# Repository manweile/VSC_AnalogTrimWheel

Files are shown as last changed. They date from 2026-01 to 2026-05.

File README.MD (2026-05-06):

# Analog Trim Wheel

A microcontroller for MSFS Flight Simulator trim tab control  

## About

I had been using my Thrustmaster TWCS dial axis as the trim wheel controller in Microsoft Flight Simulator.  
However, it is way to small of diameter - the sensitivity makes it nearly impossible to use.  
Trying to adjust the sensitivity response just wasn't working either.  

So I went searching for a microcontroller project and found [Trim Wheel Pro](https://makers-point.com/3d-prints/trim-wheel-pro/).  
The large diameter wheel and 360 degree non-contact angle sensor attached to it were exactly the solution I needed.  
The Arduino Pro Micro met my needs for the USB HID device. Since I am a retired developer, programming the Arduino was no issue.  
However, I did not own a 3d printer at the time. My son-in-law owns several, he borrowed me one, and I ended up buying a newer model of it.  

This project was also as much for learning how to break free of Microchip Studio as building a trim wheel controller.  
Refer to the [Environment README](https://github.com/manweile/VSC_AnalogTrimWheel/blob/master/Documentation/Programming%20Environment/README.MD) file for details.  

Bottom line, this project gave me a proper trim wheel control for MSFS and will make future AVR mcu development far easier.  

## Bill of Materials

|Item|Count|Link|Part Number|
|-|-|-|-|
|Rotary Hall Angle Sensor|1|[Rotary Hall Angle Sensor](https://www.aliexpress.com/item/4000143910873.html)|P3022-V1-CW360|
|Arduino Pro Micro|1|[Arduino Pro Micro](https://www.amazon.ca/ATmega32U4-Replace-ATmega328-Leonardo-Interface/dp/B0FLLNVNFL)|Arduino Pro Micro 5V|
|M3 Bolts & Nuts|1|[Glarks](https://www.amazon.ca/dp/B01J7NM9JA?ref=ppx_yo2ov_dt_b_fed_asin_title&th=1)|Glarks 230 Pc M3 Bolts and Nuts|
|White Lithium Grease|1|[White Lithium Grease](https://www.amazon.ca/dp/B004X70LZA?ref=ppx_yo2ov_dt_b_fed_asin_title)|Lucas White Lithium Grease|
|Creality Hi Combo|1|[Creality Hi Combo](https://www.reprapwarehouse.com/)|Creality Hi Combo|
|SWD Breakout Board|1|[Adafruit SWD Cable Breakout Board](https://www.adafruit.com/product/2743)|2743|
|AVR ISP Adapter|1|[Adafruit AVR 6 Pin ISP Adapter](https://www.adafruit.com/product/1465)|1465|
|Female Headers|10|[Sparkfun Female Headers](https://www.sparkfun.com/products/115)|PRT-00115|
|Mini Pushbutton Switch|1|[Sparkfun Mini Pushbutton](https://www.sparkfun.com/products/97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)|COM-0097|
|Atmel-ICE Debugger|1|[Digikey Atmel-ICE Basic](https://www.digikey.ca/en/products/detail/microchip-technology/ATATMEL-ICE-BASIC/4753381?productid=4753381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)|ATATMEL-ICE-BASIC-ND|

## Todo's

1. remove usb serial port so device appears solely as HID-compliant game controller/USB input device
   1. this will require using Atmel-Ice for uploading
2. rename to trim wheel pro
   1. this will require changing boards.txt entries

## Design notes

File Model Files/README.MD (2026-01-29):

# 3D Printing for Analog Trim Wheel
## Source
https://www.printables.com/model/709536-trim-wheel-for-flight-simulator-hall-effect-sensor

## Printers
Creality Hi Combo

## Filaments
PETG and PLA

## Slicer Software
Creality Print 7.0

## Instructions
No supports for all printed objects.  
This did require some orientation changes, depending on which part.  
Used 0.12 mm layer height for both filaments.  

### Base
Printed in black PLA and PETG.  
Oriented on bottom face.  

### Lid
Printed in black PLA and PETG.  
Oriented on back face.  
Creality Print kept giving unsupported cantilevers error when oriented on top face or 45 degrees face.  
PETG also give me grief with extraneous filaments, especially in the nut pockets.  
Required lowering print speeds (initial and general), max extruder temperature, and infill pattern (needed gyroid).  
This could all be result of using Creality printer with a generic PETG.  
The designer used a Prusa MK3S at 0.2mm layer height.  

### Wheel
I printed the wheel in PLA only because I had that in white.  
Printing in white allowed me to write (with marker) on the wheel.  
A further modification could be use the embossing feature in Creality Print, oriented on non-shaft face.  
The flat keyed shaft hole did a very small ridge in it (where the wheel transitions to axle) which I had to remove.  

### Tensioner
Printed in black PLA and PETG.  
Oriented on side, with nut pocket opening exposed.  
For PETG, required inner & outer brim.  
PETG also had plate adhesion issues - Creality Print gave "please apply glue before print" warning.  
I didn't and did have the print job become unstuck several times until I increased bed temperature to max.  

### Spacer
Printed in black PLA and PETG.  
For PETG, required inner & outer brim.  
PETG also had plate adhesion issues - Creality Print gave "please apply glue before print" warning.  
I didn't and did have the print job become unstuck several times until I increased bed temperature to max.  

### Clamp
I got the clamp from Creality Cloud, but I'm sure you can find something suitable elsewhere.  

Printed in both PETG & PLA, and in black and white.  
Totally your choice of filament and colour.  

2 different size options  
- 2.75 inch vise
- 3 inch vise

Make sure to print the vise WITHOUT supports!  
Screw hole will be plugged up if you do, and good chance will not be usable.  

## Overall Results
PLA was better than PETG.  
- No filaments in nut pockets
- Faster
- No plate adhesion issues

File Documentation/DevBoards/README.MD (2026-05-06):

# Custom USB Device

The promicro does NOT have it's own entry in the arduino boards.txt file.  
This means when you hook up an Arduino Pro Micro, what you will see in Devices & Printers is Arduino Leonardo.  

## IMPORTANT

Creating a promicro entry in boards.txt has ramifications!
Boards.txt defines the characteristics and parameters of different Arduino boards and microcontrollers.  
It tells the Arduino IDE and Arduino-CLI  how to:

- compile
- link
- upload code

This WILL impact any VS Code c_cpp_properties.json, tasks.json or launch.json functionality for Arduino-CLI.  
Specifically any inputs looking for fully qualified board name arduino:avr:promicro or build directory arduino.avr.promicro  

A Pro Micro is just a renamed Leonardo!  
You only want to change the .name, .pid.3, .build.pid, .build.usb_product, and .build.usb_product values.  
You can optionally add promicro.build.usb_manufacturer.  

## Setting custom USB device name

1. Modify Arduino Board Configuration
   1. Ensure Arduino IDE is closed
   2. Locate the boards.txt file  
      Usually in C:\users\USERNAME\AppData\Local\Arduino15\packages\arduino\hardware\1.8.x,
      where USERNAME is your user name and 1.8.x is the version of Arduino AVR Boards installed by Arduino IDE.  
      You can get the version by checking Boards Manager in Arduino IDE.  
   3. Create a custom board entry  
      Copy the existing leonardo (and not leonardoeth) definition lines to end of board.txt file.  
      In the new custom board entry, edit all "leonardo" entries to "promicro"  
   4. Change promicro.name=Arduino Leonardo to promicro.name=Arduino Pro Micro
   5. Change promicro.pid.1=0x8036 to promicro.pid.1=0x8035
   6. Change promicro.build.pid=0x8036 to leonardo.build.pid=0x8035  
      You want a unique pid.  
      It's a good idea to search through out boards.txt to make sure 0x8035 is not in use.  
      If it is, do a regex search for the last digit or last two digits.  
   7. Change promicro.build.usb_product="Arduino Leonardo" to promicro.build.usb_product="Arduino Pro Micro"
   8. Optional - add promicro.build.usb_manufacturer="Arduino" underneath promicro.build.usb_product="Arduino Pro Micro"
   9. Save the boards.txt file
   10. Ensure your pro micro is plugged into USB on computer
   11. Open Arduino IDE
   12. Find & select the new custom board name Tools > Board Manager > Arduino AVR Boards
   13. Upload a sketch (preferably the analog trim wheel sketch!)
   14. Close Arduino IDE

## Resulting Arduino Pro Micro Entry in Boards.txt

promicro.name=Arduino Pro Micro  

promicro.vid.0=0x2341  
promicro.pid.0=0x0036  
promicro.vid.1=0x2341  
promicro.pid.1=0x8035  
promicro.vid.2=0x2A03  
promicro.pid.2=0x0036  
promicro.vid.3=0x2A03  
promicro.pid.3=0x8035  

promicro.upload.tool=avrdude  
promicro.upload.protocol=avr109  
promicro.upload.maximum_size=28672  
promicro.upload.maximum_data_size=2560  
promicro.upload.speed=57600  
promicro.upload.disable_flushing=true  
promicro.upload.use_1200bps_touch=true  
promicro.upload.wait_for_upload_port=true  

promicro.bootloader.tool=avrdude  
promicro.bootloader.low_fuses=0xff  
promicro.bootloader.high_fuses=0xd8  
promicro.bootloader.extended_fuses=0xcb  
promicro.bootloader.file=caterina/Caterina-Leonardo.hex  
promicro.bootloader.unlock_bits=0x3F  
promicro.bootloader.lock_bits=0x2F  

promicro.build.mcu=atmega32u4  
promicro.build.f_cpu=16000000L  
promicro.build.vid=0x2341  
promicro.build.pid=0x8035  
promicro.build.usb_product="Arduino Pro Micro"  
promicro.build.usb_manufacturer="Arduino"  
promicro.build.board=AVR_LEONARDO  
promicro.build.core=arduino  
promicro.build.variant=leonardo
promicro.build.extra_flags={build.usb_flags}

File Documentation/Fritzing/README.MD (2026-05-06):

# Fritzing

Yeah, I know some dev's look down on Fritzing, and I don't blame them. The program does indeed have drawbacks.
But it's biggest pro is the intuitive breadboard view, and the ease of use compared to ANY cad program.

## JTAG and ISP

Atmel wants to gouge a pretty penny for connectors, which I refuse to pay.  

Luckily, Adafruit has a [SWD breakout](https://www.adafruit.com/product/2743) that you can adapt for JTAG use.  
All that you need to do is pay attention to the pin mapping specified in Atmel-ICE documentation.  

Adafruit also has an [ISP breadboard adapter](https://www.adafruit.com/product/1465), perfect for ISP.  

Both breakouts are for use with Atmel-ICE with flat jtag/isp cable.  
You can attach both the 10 pin header and 6 pin header.  

## Micro

The micro does have a dedicated ISP header, you can use it or the regular edge pins.  
For JTAG, use the regular edge pins.
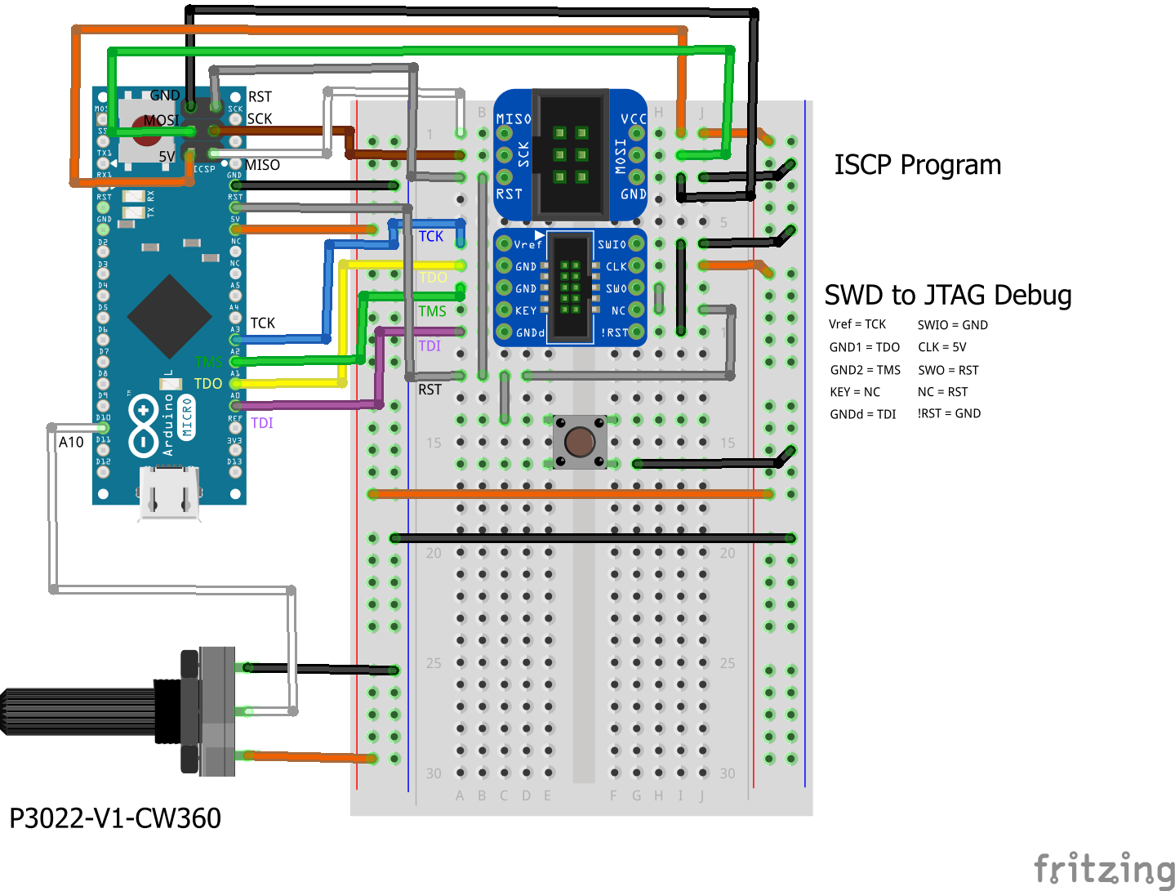
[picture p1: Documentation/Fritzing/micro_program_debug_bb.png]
Micro JTAG ISP


If you put anything in the regular edge pins next to the ISP header, you can't use the Atmel-ICE flat cable ISP connector.  
It's got a keyway that protrudes, and will prevent you from getting proper electrical connection.  
Hence the ISP breadboard adapter.  

## Pro Micro

The promicro does not have a dedicated ISP header, use the regular edge pins.  
For JTAG, use the regular edge pins.  

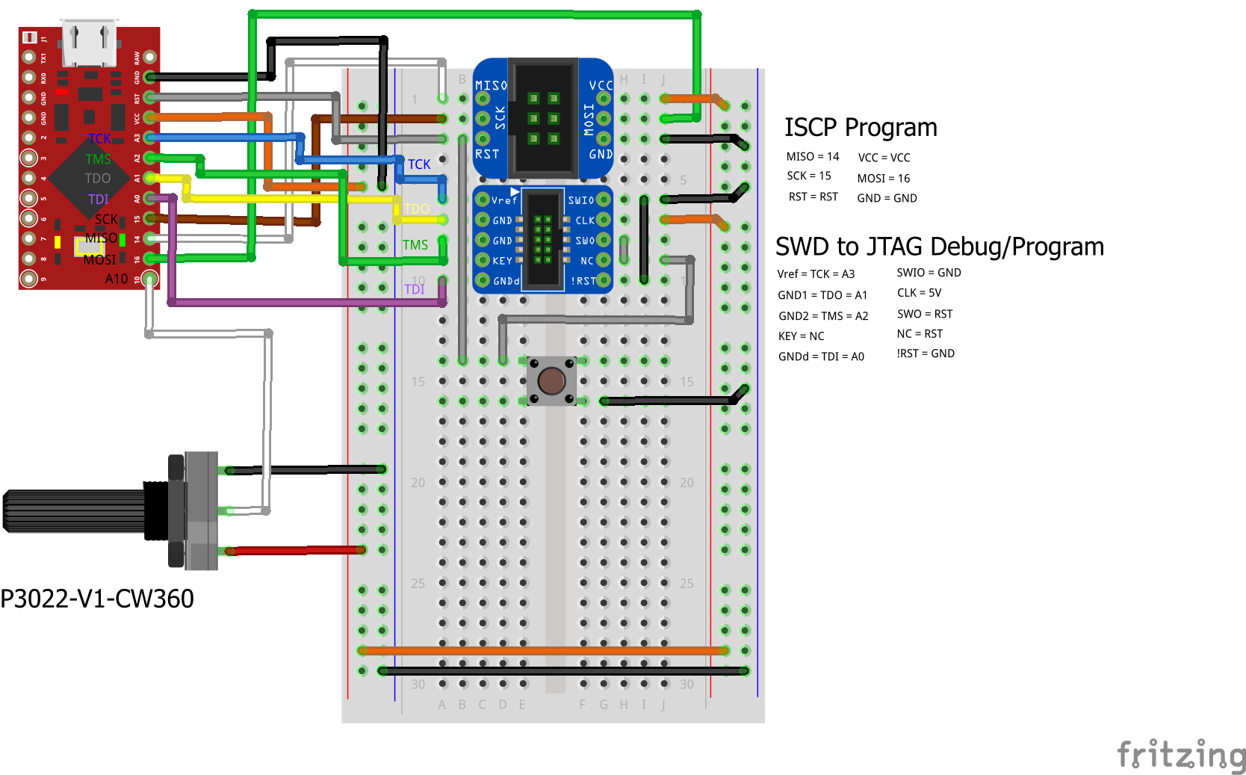
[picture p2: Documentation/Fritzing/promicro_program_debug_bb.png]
Promicro JTAG ISP


### SWD for JTAG and ISP

My Atmel-ICE flat cable ISP developed a broken wire somewhere, which rendered the ISP connection unusable.  
Fortunately, after reviewing the Atmel-ICE documentation, I realized a SWD header can supply signal for both JTAG and ISP.  

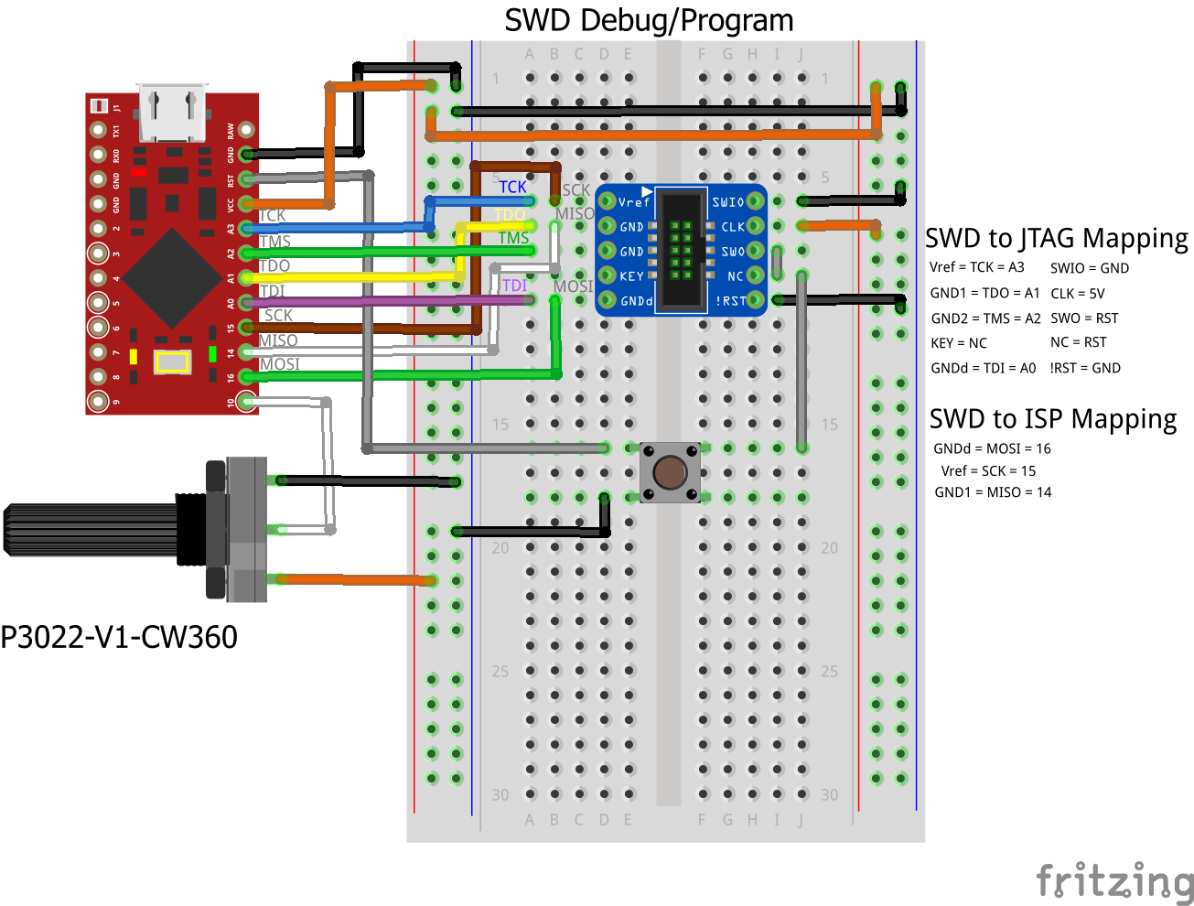
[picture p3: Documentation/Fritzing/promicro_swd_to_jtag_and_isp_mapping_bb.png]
Promicro SWD Debug/Program


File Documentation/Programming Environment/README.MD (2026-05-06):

# Programming Environment

## About

This project was as much for learning how to break free of Microchip Studio as building a trim wheel controller.

## Tools Used

- Atmel-ICE
- Arduino IDE
- avr toolchain (avr-gdb, avr-gcc, avrdude)
- Arduino-CLI
- AVRDUDESS (optional, but recommended)
- VS Code & Extensions
- AVaRICE
- MYSYS2
- WSL2

## Atmel-ICE

I know there are other hardware programmer/debuggers available, but the Atmel-ICE is for AVR/SAM mcu's.  

The Arduino Pro Micro and Micro both have JTAG and ISP pins broken out.  
So do the Mega2560 and Uno - but you can't easily use them for a HID application.  
I am presuming you've already installed drivers for you Atmel-ICE per Microchip's [install instructions](https://www.microchip.com/en-us/development-tool/atatmel-ice).  

## ArduinoIDE

Let's face it, the [Arduino IDE](https://www.arduino.cc/en/software/) is the sandbox.  
It's where you start, but you sure as hell out grow it quickly.  
It does have it's uses though - quick way to get the avr tools (avr-gcc, avr-gdb, avrdude), third party libraries, board management, etc.  
You're going to need it installed anyways if you want to do arduino coding with Microchip Studio.

## AVR Toolchain

### Arduino AVR Toolchain

I prefer the arduino avr toolchain. Why?  
Because it's maintained, compiled for Windows, works with my arduino boards, it's reasonably documented, it's easy to update.  
You can update the Arduino IDE itself, which might update your tool chain. This is the easiest way to update.  

Personally, I like the 7.3.0-atmel3.6.1-arduino5 toolchain that came with installing Arduino IDE 2.2 version.  

You can [manually update the toolchain](https://github.com/arduino/toolchain-avr/tags), just download the zip file for the version you want.  
You WILL have to compile for your preferred OS, and that's an exercise I will leave to you.  
Look at the Readme.md file in your download for details.  

Of course you will also have to install the new compile in the correct location for your OS.  

- On Windows: C:\Users\USERNAME\AppData\Local\Arduino15\packages\arduino\tools
- On Linux (Ubuntu): /HOME/USERNAME/.arduino15/packages/arduino/tools/

Just remember if you any environment variables looking at toolchain path locations, you'll need to edit them!  

### Manual AVR toolchain

Many variations here, [AVR Toolchain on Windows](https://www.tonymitchell.ca/posts/setup-avr-toolchain-on-windows/) is a good source of info & guidance.  

The major advantage of manually installing the toolchain is the pathing.  
You get to choose directory names, which means shorter and not highly specific.  

C:\AVR\avr8-gnu-toolchain\bin  
vs  
C:\Users\USERNAME\AppData\Local\Arduino15\packages\arduino\tools\avr-gcc\7.3.0-atmel3.6.1-arduino5\bin  

Downside is you might need to do some Linux on Windows setup - be it WSL2, Cygwin, MYSYS2, MINGW, etc.  
Again, don't forget about those environment variables!  

## AVRDUDE

[Avrdude (AVR Downloader Uploader)](https://avrdudes.github.io/avrdude/) is a program for downloading and uploading the on-chip memories of Atmel’s AVR microcontrollers.  
It's what Microchip Studio and Arduino IDE (and Arduino-CLI) use under the hood to get code onto your mcu.
Avrdude is a command line application, and easily used with VS Code tasks.

It comes with the Arduino AVR toolchain, which is a good reason to install the Arduino IDE.  
Otherwise you have to select a version from [Avrdudes](https://github.com/avrdudes/avrdude/releases) and manually install.  

## Arduino-CLI

Arduino-CLI is an all-in-one command line solution that's the hidden motor in Arduino IDE.  
Arduino-CLI provides Boards/Library Managers, sketch builder, board detection, uploader, and many other tools.  
However, an Arduino IDE installation does NOT give you command line access. Not sure why Arduino did that.  
This forces you to a manually install if you want to leverage it into VS Code.  
The [documentation](https://docs.arduino.cc/arduino-cli/) is adequate, but sure would like to find a well formatted pdf.

The beauty of arduino-cli is you can do so much with it from VS Code tasks!  
What's more, Arduino replaced make with arduino-cli compile functionality, it's actually easier to compile with.  

### arduino-cli.yaml

The yaml configuration file is probably the most important step in the arduino-cli install process.  
It's also something that could use better [documentation!](https://docs.arduino.cc/arduino-cli/configuration/)  

I found the important sections of the yaml file were:

- board manager
  - additional urls
        This where every board you want to work with needs to be.  
        The listing is also exactly what you put into the Arduino IDE preferences Additional boards manager URLS.  
        Literally copy from and paste into yaml file.
- directories
  - builtin
    - libraries
        The path to your builtin Arduino Libraries.  
        C:\Users\USERNAME\AppData\Local\Arduino15\libraries
  - data  
        the path to your Arduino directory used to store Boards/Library Manager index files and Boards Manager platform installations.  
        C:\Users\USERNAME\AppData\Local\Arduino15
  - downloads  
        directory used to stage downloaded archives during Boards/Library Manager installations.  
        C:\Users\USERNAME\AppData\Local\Arduino15\staging
  - user  
        the equivalent of the Arduino IDE's "sketchbook" directory.  
        You can copy from Arduino IDE preferences and paste it into yaml file.

## AVRDUDESS

[AVRDUDESS](https://blog.zakkemble.net/avrdudess-a-gui-for-avrdude/) is a gui wrapper for avrdude.  

Optional, but recommended, it is quite useful when you have something kinda one off thing that you don't have a VS Code task configured for.

- restoring boot loaders
- setting fuses  
- general mcu problem solving (ie unbricking!)

For fuses, you just have to be aware that in AVRDUDESS, a 1 for fuse actually means unset, and a 0 means set!  
In this aspect Microchip Studio's device programming dialog is actually more intuitive ... if you don't mind the baggage that comes with.  

AVRDUDESS is Windows centric, but you can get it onto Ubuntu - refer to the [AVRDUDESS readme](https://github.com/avrdudes/avrdude/blob/main/README.md).

## VSCODE

Why?

- Because it's hella easier to use than Microchip Studio
- It's better than Arduino IDE
- It's multi-OS
  - Windows
  - Ubuntu (either free-standing or via WSL2)
- I have 10 years of experience with it
- Fantastic amount of extensions
- And it's free!  

Far and away the devil I know and comprehend.  
Sure the documentation could be better, but hey, isn't all software like that?

### Extension Successes

- [C/C++](https://marketplace.visualstudio.com/items?itemName=ms-vscode.cpptools)  
      Required, need this for Intellisense and debugging.
- [Command Variable](https://marketplace.visualstudio.com/items?itemName=rioj7.command-variable)  
      Optional, but highly recommended for command and/or variable substitution in tasks and launch json files.  
      Allows you you really leverage external functionality.  
- [WSL](https://marketplace.visualstudio.com/items?itemName=ms-vscode-remote.remote-wsl)  
      Optional if you want to build Linux applications that run on WSL without the hassle of dual booting or a full virtual machine.  
      Required to use Ubuntu AVaRICE with Atmel-ICE, but comes with usb connectivity issue to the Atmel-ICE. More on that later.  

### Extension Failures

- [PlatformIO](https://marketplace.visualstudio.com/items?itemName=platformio.platformio-ide)  
    Couldn't get it to work for my AVR mcu's or with Atmel-ICE.  
    From the PlatformIO documentation, it really looks like really optimized for SAM/ARM mcu Arduino's, but not AVR mcu's.  
    Also looks like might be the go to for ESP32 mcu's which I do have.  

- [Arduino Community Edition](https://marketplace.visualstudio.com/items?itemName=vscode-arduino.vscode-arduino-community)  
    Gave me nothing but grief.  
    Actually bricked my micro and pro micro boards.  
    Appears to be really optimized for SAM/ARM mcu Arduino's, but not AVR mcu's.

## System Environment

### Variables

You can create and use custom environment variables that your c_cpp_properties.json, tasks.json and launch.json can use.  

Note if you update a path pointed to by a custom environment variable, you have to update the variable!  

You need to name the custom variable ARDUINO_  
Be aware that the Arduino-CLI can use custom variables too.  
Eg. ARDUINO_DIRECTORIES_USER, which is D:\MyArduino\Projects on my computer.  
Make sure you are not conflicting, refer to [configuration keys](https://docs.arduino.cc/arduino-cli/configuration/#configuration-keys) to check!

- ARDUINO_HARDWARE_BOOTLOADERS:  
    C:\Users\USERNAME\AppData\Local\Arduino15\packages\arduino\hardware\avr\1.8.2\bootloaders
- ARDUINO_HARDWARE_CORES:  
    C:\Users\USERNAME\AppData\Local\Arduino15\packages\arduino\hardware\avr\1.8.2\cores
- ARDUINO_HARDWARE_LIBRARIES:  
    C:\Users\USERNAME\AppData\Local\Arduino15\packages\arduino\hardware\avr\1.8.2\libraries
- ARDUINO_HARDWARE_VARIANTS:  
    C:\Users\USERNAME\AppData\Local\Arduino15\packages\arduino\hardware\avr\1.8.2\variants
- ARDUINO_LIBRARIES:
    D:\MyArduino\Projects\Libraries
- ARDUINO_TOOLS:  
    C:\Users\USERNAME\AppData\Local\Arduino15\packages\arduino\tools
- ARDUINO_TOOLS_AVRGCC_BIN:  
  C:\Users\USERNAME\AppData\Local\Arduino15\packages\arduino\tools\avr-gcc\7.3.0-atmel3.6.1-arduino5\bin

Now I can use these system variables in the c_cpp_properties.json, tasks.json or launch.json and NOT have to put in a long ass OS specific path.  
You still have to maintain the path no matter what, but now it's only in 1 place.  

### PATH

To use applications like arduino-cli, avr-gdb, avrdude, etc., in VSCode tasks.json and launch.json files, you must have them in your path.  
User or Environment really doesn't matter, so long as they are available.

### c_cpp_properties.json

This where you get you Intellisense from!  
Specifically, if you have 3rd party libraries, you need to put their paths here.  
Refer to:

- [C/C++ for Visual Studio Code](https://marketplace.visualstudio.com/items?itemName=ms-vscode.cpptools)  
- [C++ extension settings reference](https://code.visualstudio.com/docs/cpp/customize-cpp-settings)

### tasks.json

Tasks.json is where you get to leverage command line scripts and external tools.  
Refer to [Integrate External Tools via Tasks](https://code.visualstudio.com/docs/debugtest/tasks) for documentation.

### launch.json

Launch.json is where the debugging magic happens.  
Refer to [Launch Configurations](https://code.visualstudio.com/docs/debugtest/debugging-configuration) for documentation.  
I also found google AI searches helpful (so long as you watch out for "hallucinations").  

## AVaRICE

AVaRICE was the winner (no shit sherlock, literally made for AVR mcu's and Atmel-ICE!) over [OpenOCD](https://openocd.org/) and [pyOCD](https://pyocd.io/).  
I never tried [Bloom](https://bloom.oscillate.io/) - found out about it after I got AVaRICe working, and it's Linux only.  

The major issue with AVaRICE was operating system flavour.  
With Ubuntu, the usual sudo apt update && sudo apt upgrade -y followed by sudo apt install avarice works fine.  
The problem after that was Atmel-ICE is very much a Windows tool - interfacing across WSL2 to use the Atmel-ICE is kludgy.  
More on that in [AVaRICE on WSL2](#avarice-on-wsl2).

With Windows ... oh dear.  
The primary grief was the libhidapi library - getting it via Cygwin, MYSYS, or GetGNUWin32 proved to be impossible.  

AVaRICE github has documentation saying you can use Cygwin to compile.  
When you read closer, it's a much older version of Cygwin (cygwin 1.3.22-1).

GetGNUWin32 just didn't work. Ended up uninstalling it.  

MYSYS actually worked!  

## MYSYS2

[MYSYS2](https://www.msys2.org/) brings powerful, Linux-style development tools and package management to Windows users.  
MYSYS2 simplifies the process of creating native applications.  
Installation is straightforward, use is very easy.  

### AVaRICE on MYSYS2

AVaRICE on MYSYS2 worked when I dug into the github workflow logs.  
Beautiful template on how to compile and use AVaRICE.  
Upshot is libhidapi is replaced, but you have to compile 3 different libraries before you compile AVaRICE.  

You will have to run AVaRICE in a MYSYS2 MYSYS shell, but it works quite well, command line and in tasks/launch json files.  
The payoff is you can stay entirely in Windows - no arcane interfacing with Atmel-ICE required!  

Refer to [MYSYS2 Avarice compilation.txt](https://github.com/manweile/VSC_AnalogTrimWheel/blob/master/Documentation/Programming%20Environment/MYSY2%20Avarice%20compilation.txt)

## WSL2

Plenty of good documentation from Microsoft: [wsl2](https://learn.microsoft.com/en-us/windows/wsl/install).
Installation is straightforward, configuration can take little time, but is worth it.  
WSL2 offers a full Linux environment directly on Windows using a light weight virtual machine.  

### AVaRICE on WSL2

AVaRICE on WSL2 Ubuntu works, downside is still had to jump through some hoops to run on Windows.

- The installation of AVaRICE is quite painless
  - but have to do some fancy dancing with usbipd-win to get communication with the Atmel-ICE.
This setup is somewhat kludgey
- have to revert the usbipd configuration to restore normal Windows operation with Atmel-ICE, arduino-cli & avrdude.  

Needs further investigation to see if I can do the usbipd configuring in VS code launch and tasks operations.  

Follow the [WSL Avarice installation.txt](https://github.com/manweile/VSC_AnalogTrimWheel/blob/master/Documentation/Programming%20Environment/WSL%20Avarice%20installation.txt) file.  
Follow the [JTAG_ICE setup and use from WSL.txt](https://github.com/manweile/VSC_AnalogTrimWheel/blob/master/Documentation/Programming%20Environment/JTAG_ICE%20setup%20and%20use%20from%20WSL.txt) file to run AVaRICE on WSL2.  

Bottom line, it works, and it is a Ubuntu solution if that's your bent.  

## Other Tools

### IDES

### Microchip Studio

Microchip is no longer updating it, and promoting switching to MPLAB. No thank you.  
It's only for Microchip mcu's anyways, and really is overkill for almost all development tasks.  
What it is good for is going deep into the bare metal, registers, ports, and assembly code.  
I will grant the device programming dialog GUI is easier to use with Atmel-ICE than avrdude, and about equal with AVRDUDESS GUI.

### Visual Micro

[Visual Micro](https://www.visualmicro.com/) is a paid extension for MicroChip Studio/Visual Studio.  
While it does help MicroChip Studio, it has it's own learning curve and foibles.  
And you can't have an simultaneous install of the extension in both Microchip Studio and Visual Studio.  
It's one or the other, and furthermore, you can only swap once per month!

### Visual Studio

VS Code's big brother might be an option worth looking into.  
VSCode extensions are not Visual Studio compatible. Sure would be nice if they were.  
Personally, I'm not fond of the default layout of VS 2026 - I actually prefer older versions like 2017/2019.  
BTW, Microchip Studio is a port of Visual Studio. Not sure how Microchip pulled that off.  

### Eclipse

No, just no. Been there, done that with Java.
I find Eclipse a real PITA to configure. Don't even want to try for avr mcu's.  

### Interfacing Software

To hardware debug with Atmel-ICE, you need interfacing software between Atmel-ICE, avr-gdb, and your mcu.  

### pyOCD

[pyOCD](https://pyocd.io/) was a non-starter, I simply could not get it to work.  
A pity, because I really liked the os-agnosticism inherent to a python app.
Uninstalled, but going to keep an eye on it in case it gets usable.  

### OpenOCD

[OpenOCD](https://openocd.org/) was far more promising, but still only a partial success.  
Supposedly, Microchip Studio uses OpenOCD "under the hood".  
I couldn't get native OpenOCD to work with my Arduino Micro & Pro Micro (atmega32u4).  

Documentation is conflicting on OpenOCD working with AVR mcu's.  
It really appears to be slanted to SAM/ARM mcu's, which I don't have any of (yet).  
Keeping it around for the potential to work with ESP32 mcu's, which I do have.  

### Bloom

I never tried [Bloom](https://bloom.oscillate.io/), found it after I had AVaRICE working.  At first glance, it looks good.  
I like the Insight GUI, which is something that could rival Microchip Studio for serious bare metal work.  
The caveat with Bloom is that it is Linux only, and I already have that with AVaRICE.  
Going to keep an eye on it though for a Windows port.

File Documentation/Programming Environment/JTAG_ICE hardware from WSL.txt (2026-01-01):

Ensure your JTAG/ICE hardware is accessible within the WSL environment

#########################################################################################################
open an admin powershell terminal

#########################################################################################################
Install usbipd-win:
PS C:\Users\gmanw> winget.exe install --interactive --exact dorssel.usbipd-win
Found an existing package already installed. Trying to upgrade the installed package...
Found usbipd-win [dorssel.usbipd-win] Version 5.3.0
This application is licensed to you by its owner.
Microsoft is not responsible for, nor does it grant any licenses to, third-party packages.
Downloading https://github.com/dorssel/usbipd-win/releases/download/v5.3.0/usbipd-win_5.3.0_x64.msi
  ██████████████████████████████  4.29 MB / 4.29 MB
Successfully verified installer hash
Starting package install...
Successfully installed

#########################################################################################################
List available devices:
Before connecting arduino micro:
PS C:\Users\gmanw> usbipd list
Connected:
BUSID  VID:PID    DEVICE                                                        STATE
1-1    044f:b687  USB Input Device                                              Not shared
1-2    231d:0200  USB Input Device                                              Not shared
1-9    044f:b679  USB Input Device                                              Not shared
1-10   6655:4101  USB Input Device                                              Not shared
1-12   03eb:2141  USB Input Device, Atmel-ICE Data Gateway                      Not shared
1-19   1058:259f  USB Mass Storage Device                                       Not shared
3-2    2341:0043  Arduino Uno (COM11)                                           Not shared
3-3    07ca:313a  Live Streamer CAM 313, Live Streamer CAM313 Microphone        Not shared

Persisted:
GUID                                  DEVICE
869c6a39-3c90-472e-95d9-bf2ae29e455b  USB Attached SCSI (UAS) Mass Storage Device

usbipd: warning: USB filter 'USBPcap' is known to be incompatible with this software; 'bind --force' will be required.

#########################################################################################################
After connecting arduino micro:
PS C:\Users\gmanw> usbipd list
Connected:
BUSID  VID:PID    DEVICE                                                        STATE
1-1    044f:b687  USB Input Device                                              Not shared
1-2    231d:0200  USB Input Device                                              Not shared
1-8    2341:8037  Arduino Micro (COM24), USB Input Device                       Not shared
1-9    044f:b679  USB Input Device                                              Not shared
1-10   6655:4101  USB Input Device                                              Not shared
1-12   03eb:2141  USB Input Device, Atmel-ICE Data Gateway                      Not shared
1-19   1058:259f  USB Mass Storage Device                                       Not shared
3-2    2341:0043  Arduino Uno (COM11)                                           Not shared
3-3    07ca:313a  Live Streamer CAM 313, Live Streamer CAM313 Microphone        Not shared

Persisted:
GUID                                  DEVICE
869c6a39-3c90-472e-95d9-bf2ae29e455b  USB Attached SCSI (UAS) Mass Storage Device

usbipd: warning: USB filter 'USBPcap' is known to be incompatible with this software; 'bind --force' will be required.

#########################################################################################################
Binding atmel-ice:
PS C:\Users\gmanw> usbipd bind --busid 1-12
usbipd: warning: USB filter 'USBPcap' is known to be incompatible with this software; 'bind --force' will be required.

#########################################################################################################
Attaching atmel-ice:
PS C:\Users\gmanw> usbipd attach --wsl --busid 1-12
usbipd: info: Using WSL distribution 'Ubuntu' to attach; the device will be available in all WSL 2 distributions.
usbipd: info: Loading vhci_hcd module.
usbipd: info: Detected networking mode 'nat'.
usbipd: info: Using IP address 172.18.32.1 to reach the host.

#########################################################################################################
After attaching atmel-ice:
PS C:\Users\gmanw> usbipd list
Connected:
BUSID  VID:PID    DEVICE                                                        STATE
1-1    044f:b687  USB Input Device                                              Not shared
1-2    231d:0200  USB Input Device                                              Not shared
1-8    2341:8037  Arduino Micro (COM24), USB Input Device                       Not shared
1-9    044f:b679  USB Input Device                                              Not shared
1-10   6655:4101  USB Input Device                                              Not shared
1-12   03eb:2141  USB Input Device, Atmel-ICE Data Gateway                      Attached
1-19   1058:259f  USB Mass Storage Device                                       Not shared
3-2    2341:0043  Arduino Uno (COM11)                                           Not shared
3-3    07ca:313a  Live Streamer CAM 313, Live Streamer CAM313 Microphone        Not shared

Persisted:
GUID                                  DEVICE
869c6a39-3c90-472e-95d9-bf2ae29e455b  USB Attached SCSI (UAS) Mass Storage Device

#########################################################################################################
Verify device is listed in WSL terminal:
gerald@MSI-DESKTOP:~$ lsusb
Bus 001 Device 001: ID 1d6b:0002 Linux Foundation 2.0 root hub
Bus 001 Device 002: ID 03eb:2141 Atmel Corp. ICE debugger
Bus 002 Device 001: ID 1d6b:0003 Linux Foundation 3.0 root hub

#########################################################################################################
Install necessary Linux tools in WSL terminal:
gerald@MSI-DESKTOP:~$ sudo apt install linux-tools-generic hwdata

#########################################################################################################
Create udev rule in WSL terminal:

gerald@MSI-DESKTOP:~$ sudo vim /etc/udev/rules.d/99-avr-jtag.rules
# Atmel-ICE (EDBG)
SUBSYSTEM=="usb", ATTR{idVendor}=="03eb", ATTR{idProduct}=="2141", MODE="0666", GROUP="plugdev"

# AVR Dragon
SUBSYSTEM=="usb", ATTR{idVendor}=="03eb", ATTR{idProduct}=="2107", MODE="0666", GROUP="plugdev"

# JTAGICE mkII
SUBSYSTEM=="usb", ATTR{idVendor}=="03eb", ATTR{idProduct}=="2103", MODE="0666", GROUP="plugdev"

# JTAGICE 3
SUBSYSTEM=="usb", ATTR{idVendor}=="03eb", ATTR{idProduct}=="2140", MODE="0666", GROUP="plugdev"

save and exit

apply rules in WSL terminal:
gerald@MSI-DESKTOP:~$ sudo udevadm control --reload-rules && sudo udevadm trigger
gerald@MSI-DESKTOP:~$ sudo usermod -aG plugdev $USER

verify rules WSL terminal:
gerald@MSI-DESKTOP:~$ lsusb
Bus 001 Device 001: ID 1d6b:0002 Linux Foundation 2.0 root hub
Bus 001 Device 002: ID 03eb:2141 Atmel Corp. ICE debugger
Bus 002 Device 001: ID 1d6b:0003 Linux Foundation 3.0 root hub
gerald@MSI-DESKTOP:~$ ls -l /dev/bus/usb/001/002
crw-rw-rw- 1 root plugdev 189, 1 Dec 30 15:34 /dev/bus/usb/001/002

#########################################################################################################

Set mcu fuses:
Note: you can use avrdude/AVRDUDESS while you have the Atmel-Ice setup with usbipd.
You CANNOT with Microchip studio.

With AVRDUDESS:
open bit fuses; select OCDEN and JTAGEN to 0, HFUSE should now have 0x18, click write fuses.
To reverse, select OCDEN and JTAGEN to 1, HFUSE should now have 0xD8, click write fuses.

With avrdude cli:
avrdude.exe -c atmelice_isp -p m32u4 -F -v -v -U lfuse:w:0xFF:m -U hfuse:w:0x18:m -U efuse:w:0xFB:m
to reverse: avrdude.exe -c atmelice_isp -p m32u4 -F -v -v -U lfuse:w:0xFF:m -U hfuse:w:0xD8:m -U efuse:w:0xFB:m

With Microchip Studio Device Programming Dialog:
First you have to detach and unbind the Atmel-Ice with usbipd
Open device programming dialog
Tool: Atmel-Ice, Device: ATmega32u4 (for example), Interface: JTAG or ISP (depends on which you have hooked up and/or prefer). 
click device signature read, click target voltage read.
Select HIGH.OCDEN, select HIGH.JTAGEN, click Program.
To reverse, unselect HIGH.OCDEN, select HIGH.JTAGEN, click Program.

#########################################################################################################

Run AVaRICE in WSL Terminal:
gerald@MSI-DESKTOP:~$ avarice --edbg --jtag usb :4242
AVaRICE version 2.14svn20200906, Mar 28 2022 12:30:47

Defaulting JTAG bitrate to 250 kHz.

JTAG config starting.
Found a device, serial number: J41800082278
Reported device ID: 0x9587
Configured for device ID: 0x9587 atmega32u4
JTAG config complete.
Preparing the target device for On Chip Debugging.
Waiting for connection on port 4242.

#########################################################################################################

verify avr-gdb in Admin Powershell:
PS D:\MyArduino\Projects\VSC_AnalogTrimWheel\build\arduino.avr.micro> avr-gdb.exe .\VSC_AnalogTrimWheel.ino.elf
GNU gdb (GDB) 7.8
Copyright (C) 2014 Free Software Foundation, Inc.
License GPLv3+: GNU GPL version 3 or later <http://gnu.org/licenses/gpl.html>
This is free software: you are free to change and redistribute it.
There is NO WARRANTY, to the extent permitted by law.  Type "show copying"
and "show warranty" for details.
This GDB was configured as "--host=i686-w64-mingw32 --target=avr".
Type "show configuration" for configuration details.
For bug reporting instructions, please see:
<http://www.gnu.org/software/gdb/bugs/>.
Find the GDB manual and other documentation resources online at:
<http://www.gnu.org/software/gdb/documentation/>.
For help, type "help".
Type "apropos word" to search for commands related to "word"...
Reading symbols from .\VSC_AnalogTrimWheel.ino.elf...done.
(gdb) target remote localhost:4242
Remote debugging using localhost:4242
0x00007000 in ?? ()
(gdb)

AVaRICE in WSL Terminal output:
Connection opened by host 127.0.0.1, port 60094.

avr-gdb in Admin Powershell:
(gdb) quit
This will also terminate avarice, so you have to restart it in the WSL terminal.

#########################################################################################################

You can now debug in VS Code
NB Setting/unsetting the OCDEN and JTAGEN fuses is NOT required!
Launch avarice is a WSL terminal:
single use: gerald@MSI-DESKTOP:~$ avarice --edbg --jtag usb :4242
continuous: gerald@MSI-DESKTOP:~$ while true; do avarice --edbg --jtag usb :4243; sleep 1; done

Use launch task in VS Code

#########################################################################################################

To reverse Atmel-Ice setup:

Verify device is listed in WSL terminal:
gerald@MSI-DESKTOP:~$ lsusb
Bus 001 Device 001: ID 1d6b:0002 Linux Foundation 2.0 root hub
Bus 001 Device 002: ID 03eb:2141 Atmel Corp. ICE debugger
Bus 002 Device 001: ID 1d6b:0003 Linux Foundation 3.0 root hub

list devices in Admin Powershell terminal:
PS C:\Users\gmanw> usbipd list
Connected:
BUSID  VID:PID    DEVICE                                                        STATE
1-1    044f:b687  USB Input Device                                              Not shared
1-2    231d:0200  USB Input Device                                              Not shared
1-8    0000:0002  Unknown USB Device (Device Descriptor Request Failed)         Not shared
1-9    044f:b679  USB Input Device                                              Not shared
1-10   6655:4101  USB Input Device                                              Not shared
1-12   03eb:2141  USB Input Device, Atmel-ICE Data Gateway                      Attached
1-19   1058:259f  USB Mass Storage Device                                       Not shared
3-2    2341:0043  Arduino Uno (COM11)                                           Not shared
3-3    07ca:313a  Live Streamer CAM 313, Live Streamer CAM313 Microphone        Not shared

Persisted:
GUID                                  DEVICE
869c6a39-3c90-472e-95d9-bf2ae29e455b  USB Attached SCSI (UAS) Mass Storage Device

usbipd: warning: USB filter 'USBPcap' is known to be incompatible with this software; 'bind --force' will be required.

detach by hardware-id in Admin Powershell terminal:
PS C:\Users\gmanw> usbipd detach -i 03eb:2141

unbind by bus-id in Admin Powershell terminal:
usbipd: info: Device with hardware-id '03eb:2141' found at busid '1-12'.
PS C:\Users\gmanw> usbipd unbind --busid 1-12

Confirm device not listed in WSL terminal:
gerald@MSI-DESKTOP:~$ lsusb
Bus 001 Device 001: ID 1d6b:0002 Linux Foundation 2.0 root hub
Bus 002 Device 001: ID 1d6b:0003 Linux Foundation 3.0 root hub

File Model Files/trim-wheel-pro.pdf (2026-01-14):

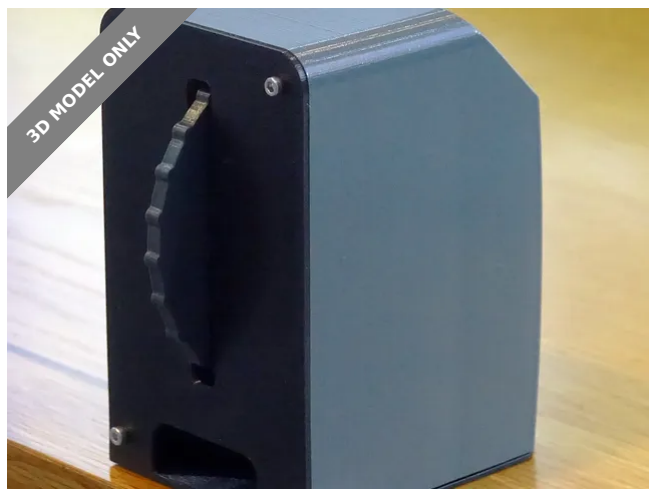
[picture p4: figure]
3D MODEL ONLY

## Summary

Trim wheel uses a hall-effect sensor connected to an Arduino Leonardo to produce highly accurate results for flight sims

Hobby & Makers (https://printables.com/model?categoryId=48) > Electronics (https://printables.com/model?categoryId=52)

Tags: | wheel | joystick | trim | halleffect | analog | analogue
flightsim | flightsimulator | arduinopromicro | trimwheel

Here are the model files for TWP (Trim Wheel Pro). It is an analogue elevator trim which can be used to precisely control the elevator trim of your aircraft in flight simulator.

More information, assembly instructions, and code can be found on my website. (https://makers-point.com/flight-sim-tools/trim-wheel-pro-guide)

All parts have been printed in PETG, on a Prusa MK3S at 0.2mm layer height. No supports are required but will require the purchase of additional components and a tiny bit of soldering.

Daedelus (https://printables.com/@Daedelus_17435)

## Trim Wheel for

flight simulator.

## Hall effect sensor is

highly accurate.
Easy to mount.

## Easy to tension

VIEW IN BROWSER (https://printables.com/model/709536-trim-wheel-for-flight-simulator-hall-effect-sensor)

updated 3. 2. 2025 | published 3. 2. 2025

## Model files

Note: I printed the base on a textured sheet to give a nice finish, the other parts I printed on a smooth sheet. The 3mf files show the printed parts in the correct print orientation but you can print each part separately if you wish.

Edit 28/01/2024: Made minor changes to tolarences / chamfers etc.

Edit 06/03/2024:

New tensioner design to use a single tensioner screw for even and convenient tensioning
Removed uneeded cap + now unneccesary countersunk screw Redesigned wheel now cap has been removed
Redsigned guide on my website to take changes into account

Enjoy!

•

•
•
•

base.3mf

main.3mf

lid.3mf

lid.stl

spacer.stl

## License

This work is licensed under a
Creative Commons (4.0 International License)

Attribution-NonCommercial (http://creativecommons.org/licenses/by-nc/4.0/)

✖ | Sharing without ATTRIBUTION
✔ | Remix Culture allowed
✖ | Commercial Use
✖ | Free Cultural Works
✖ | Meets Open Definition

tensioner.stl

wheel.stl

base.stl

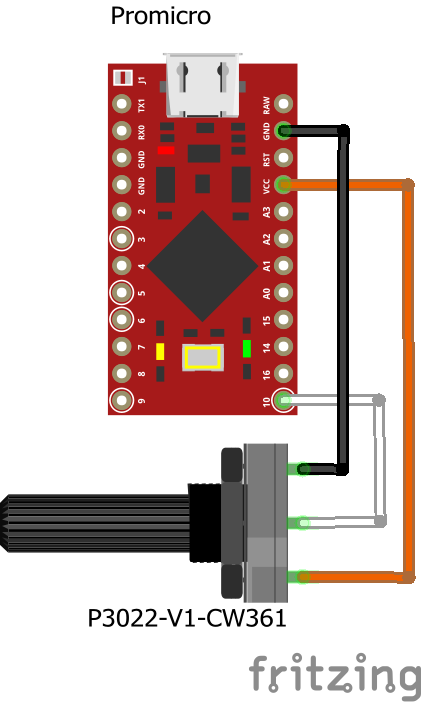
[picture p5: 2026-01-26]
Documentation/Fritzing/promicro_production_bb.png

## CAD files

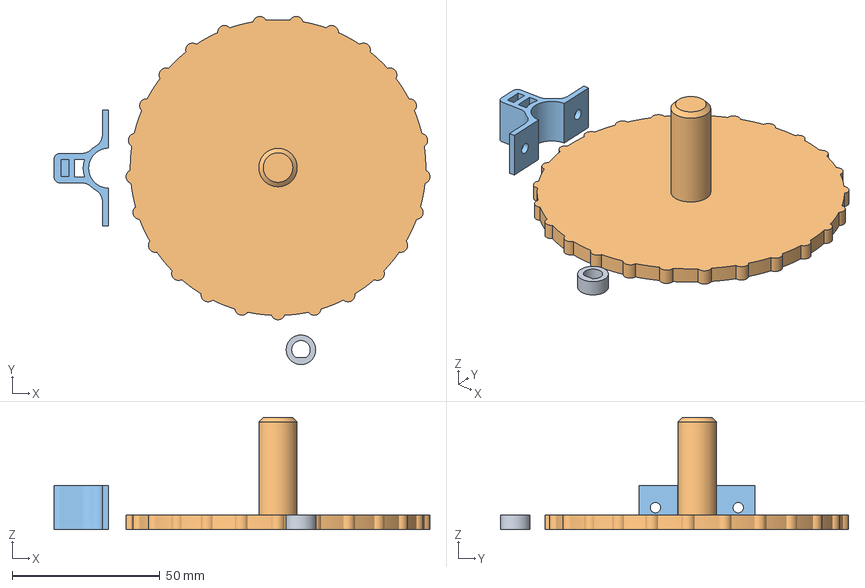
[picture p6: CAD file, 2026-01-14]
Model Files/src/src_3mf/main.3mf
127.2 x 117.7 x 38.0 mm
Spacer.stl
Wheel.stl
Tensioner.stl

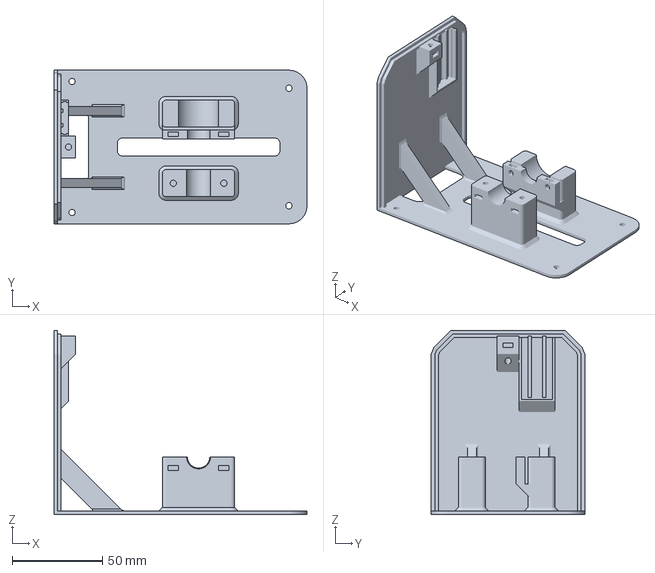
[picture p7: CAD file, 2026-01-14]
Model Files/src/src_3mf/lid.3mf
140.0 x 85.0 x 102.0 mm

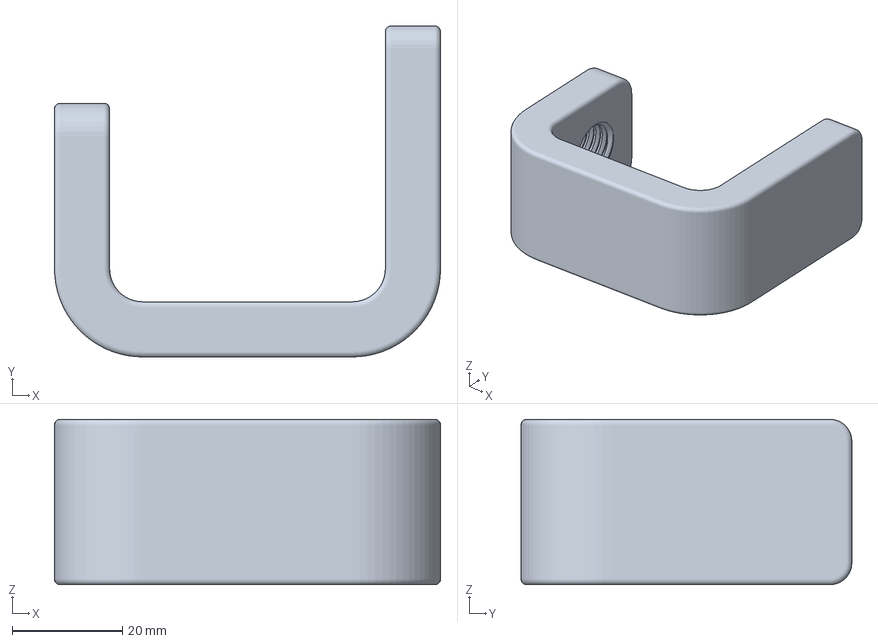
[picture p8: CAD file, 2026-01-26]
Model Files/Creality print/creality_print_3mfs/2_75 inch clamp vise.3mf
70.0 x 60.0 x 30.0 mm

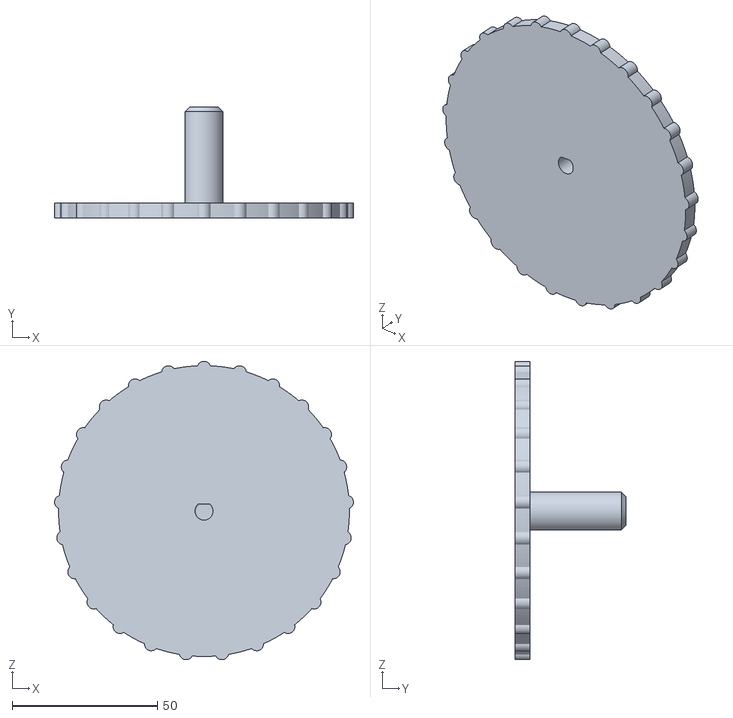
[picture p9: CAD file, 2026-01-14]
Model Files/src/src_stl/wheel.stl
102.8 x 38.0 x 102.6

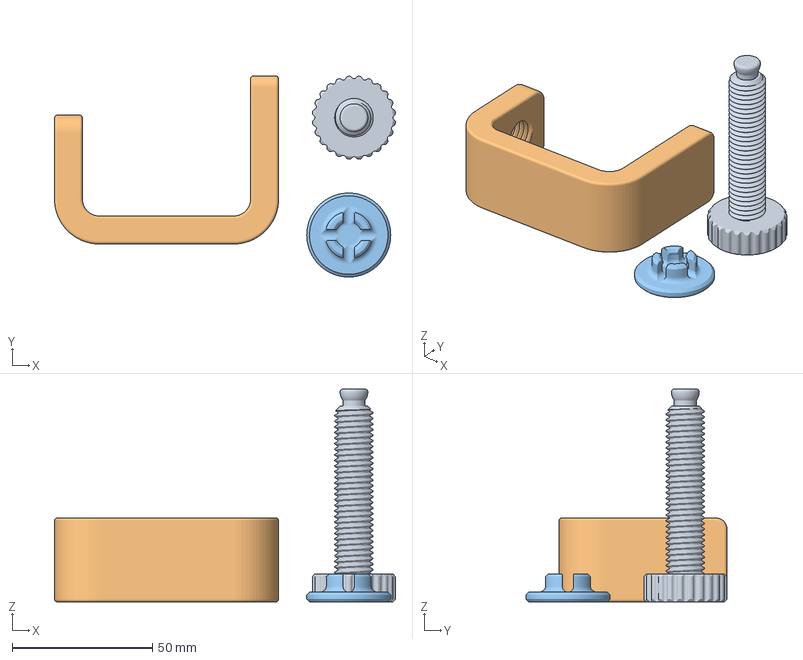
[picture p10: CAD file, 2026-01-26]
Model Files/Creality print/creality_print_3mfs/3 inch clamp.3mf
121.7 x 71.8 x 76.0 mm
Screw
Contact

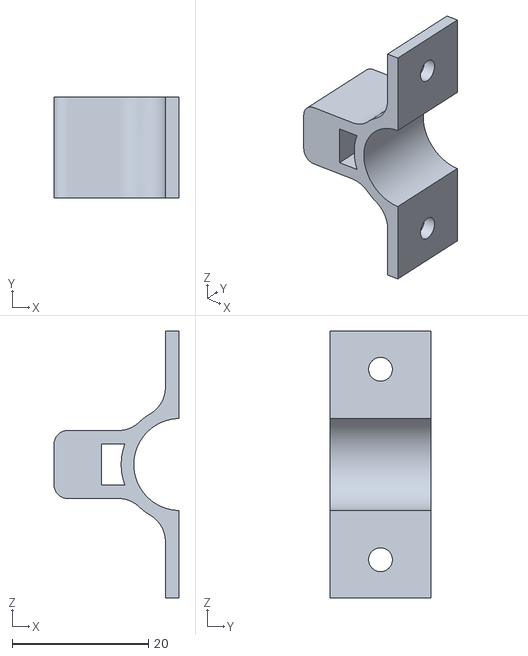
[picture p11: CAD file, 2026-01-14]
Model Files/src/src_stl/tensioner.stl
18.4 x 14.9 x 39.3

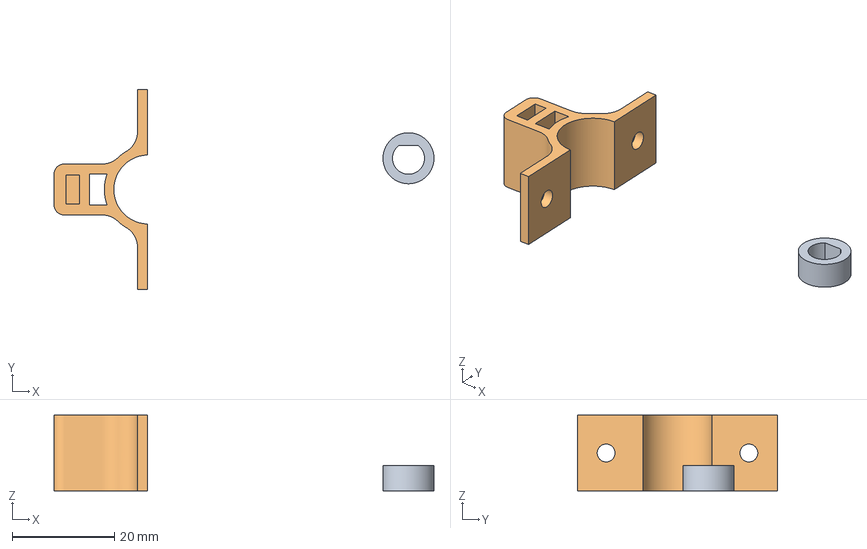
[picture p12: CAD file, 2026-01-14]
Model Files/Creality print/creality_print_3mfs/spacer_tensioner.3mf
74.5 x 39.3 x 14.9 mm
spacer.stl
tensioner.stl

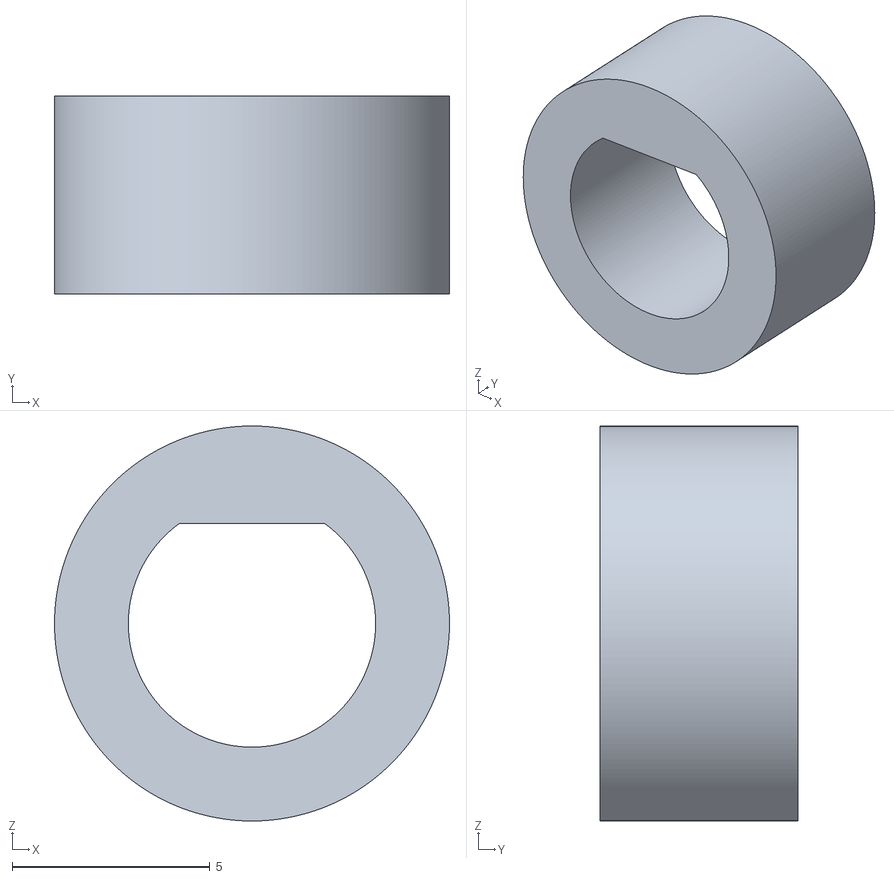
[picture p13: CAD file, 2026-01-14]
Model Files/src/src_stl/spacer.stl
10.0 x 5.00 x 10.00

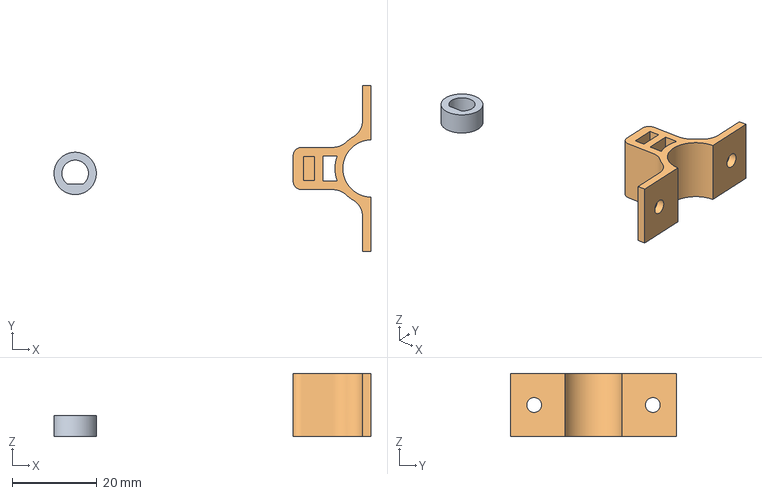
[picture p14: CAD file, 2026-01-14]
Model Files/Creality print/creality_print_3mfs/base.3mf
74.8 x 39.3 x 14.9 mm
spacer.stl
tensioner.stl

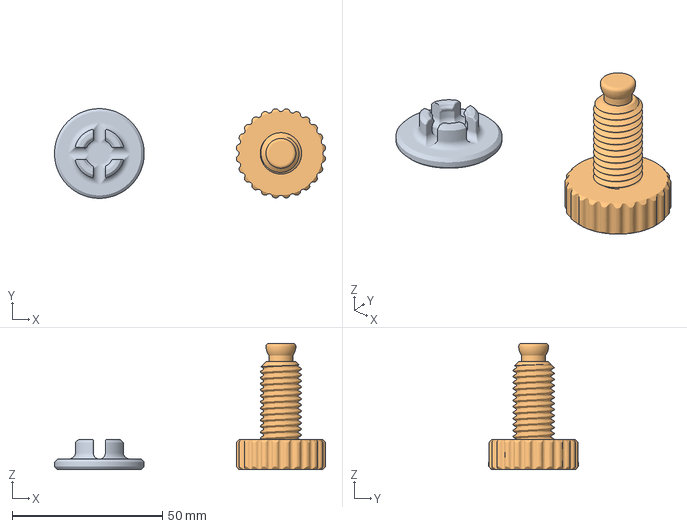
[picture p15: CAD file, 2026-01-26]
Model Files/Creality print/creality_print_3mfs/1_65 inch clamp screw and plate.3mf
90.1 x 29.9 x 42.0 mm
Contact
Clamp screw

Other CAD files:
Model Files/src/src_stl/Base_opt_arduino_micro.stl
Model Files/src/src_3mf/base.3mf
Model Files/src/src_stl/base.stl
Model Files/src/src_stl/lid.stl

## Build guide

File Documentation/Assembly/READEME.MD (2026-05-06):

# Assembly

The [assembly instructions](https://makers-point.com/3d-prints/trim-wheel-pro/trim-wheel-pro-guide/) from the creator are pretty good.  

## Tips

- Trim the solder joints on the underside of your Pro Micro. The slot for the board is quite tight, you need the vertical clearance.
- Use needle nose pliers to place the M3 nuts in their pockets. Those nuts are really small, especially if you have big hands.
- You can use female sockets on the Arduino and male ended wires on the sensor instead of male pins and female ended wires.
- I also used shrink wrap on the three wire sensor wires to bundle them, for stability prior to connecting to the Arduino.

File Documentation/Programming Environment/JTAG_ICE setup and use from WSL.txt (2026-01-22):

Ensure your JTAG/ICE hardware is accessible within the WSL environment

#########################################################################################################
open an admin powershell terminal

#########################################################################################################
Install usbipd-win:
PS C:\Users\<user> winget.exe install --interactive --exact dorssel.usbipd-win
Found an existing package already installed. Trying to upgrade the installed package...
Found usbipd-win [dorssel.usbipd-win] Version 5.3.0
This application is licensed to you by its owner.
Microsoft is not responsible for, nor does it grant any licenses to, third-party packages.
Downloading https://github.com/dorssel/usbipd-win/releases/download/v5.3.0/usbipd-win_5.3.0_x64.msi
  ██████████████████████████████  4.29 MB / 4.29 MB
Successfully verified installer hash
Starting package install...
Successfully installed

NB It's really good idea to make sure usbipd-win is in your system environment PATH.

#########################################################################################################
List available devices:
Before connecting arduino micro:
PS C:\Users\<user> usbipd list
Connected:
BUSID  VID:PID    DEVICE                                                        STATE
1-1    044f:b687  USB Input Device                                              Not shared
1-2    231d:0200  USB Input Device                                              Not shared
1-9    044f:b679  USB Input Device                                              Not shared
1-10   6655:4101  USB Input Device                                              Not shared
1-12   03eb:2141  USB Input Device, Atmel-ICE Data Gateway                      Not shared
1-19   1058:259f  USB Mass Storage Device                                       Not shared
3-2    2341:0043  Arduino Uno (COM11)                                           Not shared
3-3    07ca:313a  Live Streamer CAM 313, Live Streamer CAM313 Microphone        Not shared

Persisted:
GUID                                  DEVICE
869c6a39-3c90-472e-95d9-bf2ae29e455b  USB Attached SCSI (UAS) Mass Storage Device

usbipd: warning: USB filter 'USBPcap' is known to be incompatible with this software; 'bind --force' will be required.

#########################################################################################################
After connecting arduino micro:
PS C:\Users\<user> usbipd list
Connected:
BUSID  VID:PID    DEVICE                                                        STATE
1-1    044f:b687  USB Input Device                                              Not shared
1-2    231d:0200  USB Input Device                                              Not shared
1-8    2341:8037  Arduino Micro (COM24), USB Input Device                       Not shared
1-9    044f:b679  USB Input Device                                              Not shared
1-10   6655:4101  USB Input Device                                              Not shared
1-12   03eb:2141  USB Input Device, Atmel-ICE Data Gateway                      Not shared
1-19   1058:259f  USB Mass Storage Device                                       Not shared
3-2    2341:0043  Arduino Uno (COM11)                                           Not shared
3-3    07ca:313a  Live Streamer CAM 313, Live Streamer CAM313 Microphone        Not shared

Persisted:
GUID                                  DEVICE
869c6a39-3c90-472e-95d9-bf2ae29e455b  USB Attached SCSI (UAS) Mass Storage Device

usbipd: warning: USB filter 'USBPcap' is known to be incompatible with this software; 'bind --force' will be required.

#########################################################################################################
Binding atmel-ice:
PS C:\Users\<user> usbipd bind --busid 1-12
usbipd: warning: USB filter 'USBPcap' is known to be incompatible with this software; 'bind --force' will be required.

#########################################################################################################
Attaching atmel-ice:
PS C:\Users\<user> usbipd attach --wsl --busid 1-12
usbipd: info: Using WSL distribution 'Ubuntu' to attach; the device will be available in all WSL 2 distributions.
usbipd: info: Loading vhci_hcd module.
usbipd: info: Detected networking mode 'nat'.
usbipd: info: Using IP address 172.18.32.1 to reach the host.

#########################################################################################################
After attaching atmel-ice:
PS C:\Users\<user> usbipd list
Connected:
BUSID  VID:PID    DEVICE                                                        STATE
1-1    044f:b687  USB Input Device                                              Not shared
1-2    231d:0200  USB Input Device                                              Not shared
1-8    2341:8037  Arduino Micro (COM24), USB Input Device                       Not shared
1-9    044f:b679  USB Input Device                                              Not shared
1-10   6655:4101  USB Input Device                                              Not shared
1-12   03eb:2141  USB Input Device, Atmel-ICE Data Gateway                      Attached
1-19   1058:259f  USB Mass Storage Device                                       Not shared
3-2    2341:0043  Arduino Uno (COM11)                                           Not shared
3-3    07ca:313a  Live Streamer CAM 313, Live Streamer CAM313 Microphone        Not shared

Persisted:
GUID                                  DEVICE
869c6a39-3c90-472e-95d9-bf2ae29e455b  USB Attached SCSI (UAS) Mass Storage Device

#########################################################################################################
Verify device is listed in WSL terminal:
<user>@<computer>:~$ lsusb
Bus 001 Device 001: ID 1d6b:0002 Linux Foundation 2.0 root hub
Bus 001 Device 002: ID 03eb:2141 Atmel Corp. ICE debugger
Bus 002 Device 001: ID 1d6b:0003 Linux Foundation 3.0 root hub

#########################################################################################################
Install necessary Linux tools in WSL terminal:
<user>@<computer>:~$ sudo apt install linux-tools-generic hwdata

#########################################################################################################
Create udev rule in WSL terminal:

<user>@<computer>:~$ sudo vim /etc/udev/rules.d/99-avr-jtag.rules
# Atmel-ICE (EDBG)
SUBSYSTEM=="usb", ATTR{idVendor}=="03eb", ATTR{idProduct}=="2141", MODE="0666", GROUP="plugdev"

# AVR Dragon
SUBSYSTEM=="usb", ATTR{idVendor}=="03eb", ATTR{idProduct}=="2107", MODE="0666", GROUP="plugdev"

# JTAGICE mkII
SUBSYSTEM=="usb", ATTR{idVendor}=="03eb", ATTR{idProduct}=="2103", MODE="0666", GROUP="plugdev"

# JTAGICE 3
SUBSYSTEM=="usb", ATTR{idVendor}=="03eb", ATTR{idProduct}=="2140", MODE="0666", GROUP="plugdev"

save and exit

apply rules in WSL terminal:
<user>@<computer>:~$ sudo udevadm control --reload-rules && sudo udevadm trigger
<user>@<computer>:~$ sudo usermod -aG plugdev $USER

verify rules WSL terminal:
<user>@<computer>:~$ lsusb
Bus 001 Device 001: ID 1d6b:0002 Linux Foundation 2.0 root hub
Bus 001 Device 002: ID 03eb:2141 Atmel Corp. ICE debugger
Bus 002 Device 001: ID 1d6b:0003 Linux Foundation 3.0 root hub
<user>@<computer>:~$ ls -l /dev/bus/usb/001/002
crw-rw-rw- 1 root plugdev 189, 1 Dec 30 15:34 /dev/bus/usb/001/002

#########################################################################################################

Set mcu fuses:
Note: you can use avrdude/AVRDUDESS while you have the Atmel-Ice setup with usbipd.
You CANNOT with Microchip studio.

Note: Arduino Micro and Pro Micro have JTAG (and ISP).
The Uno does not, you have to use the debugWire (DWEN) fuse.
There is a slightly different procedure for hardware debugging an Uno, which you can find via Google search.
I'm not going into to it here because you can't easily use a Uno for a HID device application.
Also, while you can JTAG hardware debug a Mega2560, you can't easily use it for an HID application either.

With AVRDUDESS:
open bit fuses; select OCDEN and JTAGEN to 0, HFUSE should now have 0x18, click write fuses.
To reverse, select OCDEN and JTAGEN to 1, HFUSE should now have 0xD8, click write fuses.

With avrdude cli, for ATmega32u4 mcu (Arduino Micro & Pro Micro):
avrdude.exe -c atmelice_isp -p m32u4 -F -v -v -U lfuse:w:0xFF:m -U hfuse:w:0x18:m -U efuse:w:0xFB:m
to reverse: avrdude.exe -c atmelice_isp -p m32u4 -F -v -v -U lfuse:w:0xFF:m -U hfuse:w:0xD8:m -U efuse:w:0xFB:m

With Microchip Studio Device Programming Dialog:
First you have to detach and unbind the Atmel-Ice with usbipd
Open device programming dialog
Tool: Atmel-Ice, Device: ATmega32u4 (for example), Interface: JTAG or ISP (depends on which you have hooked up and/or prefer).
click device signature read, click target voltage read.
Select HIGH.OCDEN, select HIGH.JTAGEN, click Program.
To reverse, unselect HIGH.OCDEN, select HIGH.JTAGEN, click Program.

#########################################################################################################

Run AVaRICE in WSL Terminal:
<user>@<computer>:~$ avarice --edbg --jtag usb :4242
AVaRICE version 2.14svn20200906, Mar 28 2022 12:30:47

Defaulting JTAG bitrate to 250 kHz.

JTAG config starting.
Found a device, serial number: J41800082278
Reported device ID: 0x9587
Configured for device ID: 0x9587 atmega32u4
JTAG config complete.
Preparing the target device for On Chip Debugging.
Waiting for connection on port 4242.

#########################################################################################################

verify avr-gdb in Admin Powershell:
PS D:\MyArduino\Projects\VSC_AnalogTrimWheel\build\arduino.avr.micro> avr-gdb.exe .\VSC_AnalogTrimWheel.ino.elf
GNU gdb (GDB) 7.8
Copyright (C) 2014 Free Software Foundation, Inc.
License GPLv3+: GNU GPL version 3 or later <http://gnu.org/licenses/gpl.html>
This is free software: you are free to change and redistribute it.
There is NO WARRANTY, to the extent permitted by law.  Type "show copying"
and "show warranty" for details.
This GDB was configured as "--host=i686-w64-mingw32 --target=avr".
Type "show configuration" for configuration details.
For bug reporting instructions, please see:
<http://www.gnu.org/software/gdb/bugs/>.
Find the GDB manual and other documentation resources online at:
<http://www.gnu.org/software/gdb/documentation/>.
For help, type "help".
Type "apropos word" to search for commands related to "word"...
Reading symbols from .\VSC_AnalogTrimWheel.ino.elf...done.
(gdb) target remote localhost:4242
Remote debugging using localhost:4242
0x00007000 in ?? ()
(gdb)

AVaRICE in WSL Terminal output:
Connection opened by host 127.0.0.1, port 60094.

avr-gdb in Admin Powershell:
(gdb) quit
This will also terminate avarice, so you have to restart it in the WSL terminal.

#########################################################################################################

You can now debug in VS Code
NB Setting/unsetting the OCDEN and JTAGEN fuses is NOT required, you've already done it.
Launch avarice is a WSL terminal:
single use: <user>@<computer>:~$ avarice --edbg --jtag usb :4242
continuous: <user>@<computer>:~$ while true; do avarice --edbg --jtag usb :4243; sleep 1; done

Use launch task in VS Code

#########################################################################################################

To reverse Atmel-Ice setup:

Verify device is listed in WSL terminal:
<user>@<computer>:~$ lsusb
Bus 001 Device 001: ID 1d6b:0002 Linux Foundation 2.0 root hub
Bus 001 Device 002: ID 03eb:2141 Atmel Corp. ICE debugger
Bus 002 Device 001: ID 1d6b:0003 Linux Foundation 3.0 root hub

list devices in Admin Powershell terminal:
PS C:\Users\<user> usbipd list
Connected:
BUSID  VID:PID    DEVICE                                                        STATE
1-1    044f:b687  USB Input Device                                              Not shared
1-2    231d:0200  USB Input Device                                              Not shared
1-8    0000:0002  Unknown USB Device (Device Descriptor Request Failed)         Not shared
1-9    044f:b679  USB Input Device                                              Not shared
1-10   6655:4101  USB Input Device                                              Not shared
1-12   03eb:2141  USB Input Device, Atmel-ICE Data Gateway                      Attached
1-19   1058:259f  USB Mass Storage Device                                       Not shared
3-2    2341:0043  Arduino Uno (COM11)                                           Not shared
3-3    07ca:313a  Live Streamer CAM 313, Live Streamer CAM313 Microphone        Not shared

Persisted:
GUID                                  DEVICE
869c6a39-3c90-472e-95d9-bf2ae29e455b  USB Attached SCSI (UAS) Mass Storage Device

usbipd: warning: USB filter 'USBPcap' is known to be incompatible with this software; 'bind --force' will be required.

detach by hardware-id in Admin Powershell terminal:
PS C:\Users\<user> usbipd detach -i 03eb:2141

unbind by bus-id in Admin Powershell terminal:
usbipd: info: Device with hardware-id '03eb:2141' found at busid '1-12'.
PS C:\Users\<user> usbipd unbind --busid 1-12

Confirm device not listed in WSL terminal:
<user>@<computer>:~$ lsusb
Bus 001 Device 001: ID 1d6b:0002 Linux Foundation 2.0 root hub
Bus 002 Device 001: ID 1d6b:0003 Linux Foundation 3.0 root hub

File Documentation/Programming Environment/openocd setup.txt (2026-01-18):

1) ensure fuses
a) via Micro chip Studio Device Programming dialog:
Tool:               Atmel-Ice
Device:             ATmega32u4
Interface:          ISP
Device Signature:   0x1E9587
Target Voltage:     4.9 Volts

FUSES
FuseName:           Value:
EXTENDED.BODLEVEL   Brown out detection at VCC=2.6 V 2V6
EXTENDED.HWBE       off
HIGH.OCDEN          on
HIGH.JTAGEN         on
HIGH.SPIEN          on
HIGH.WDTON          off
HIGH.EESAVE         off
HIGH.BOOTRZ         Boot flash size=2048 words start address=$3800 2048W_3800
HIGH.BOOTRST        on
LOW.CKDIV8          off
LOW.CKOUT           off
LOW.SUT_CKSEL       Ext. Crystal Osc. 8.0- Mhz;Start-up time:16K CK+65 ms EXTXOSC_8MHZ__16KCK_65MS

Fuse Register:      Value
EXTENDED            0xCB
HIGH                0x18
LOW                 0xFF

LOCK BITS
Lock Bit Register:  Value:
LOCKBIT             0xFF

LOCKBIT.LB:         No memory lock features enabled
LOCKBIT.BLB0:       No lock on SPM and LPM in Application Section
LOCKBIT.BLB1:       No lock on SPM and LPM in Boot Section

b) via AVRDUDESS Fuse and Lock Bits Selector
NB 1 actually means off, 0 means on
Lock Bits:      Value:
bit7            1
bit6            1
BLB12           1
BLB11           1
BLB02           1
BLB01           1
LB2             1
LB1             1
LOCK BITS       0xFF

Fuse Bits:      Value:
CKDIV8          1
CKOUT           1
SUT1            1
SUT0            1
CKSEL3          1
CKSEL2          1
CKSEL1          1
CKSEL0          1
LFUSE           0xFF

OCDEN           0
JTAGEN          0
SPIEN           0
WDTON           1
EESAVE          1
BOOTSZ1         0
BOOTSZ0         0
BOOTRST         0
HFUSE           0x18

bit7            1
bit6            1
bit5            0
bit4            0
HWBE            1
BODLEVEL2       0
BODLEVEL1       1
BODLEVEL0       1
EFUSE           0xCB

c) via avrdude command line for atmega32u4 via atmel-ice ISP mode, LFUSE: 0xFF, HFUSE: 0x18, EFUSE: 0xCB
avrdude -c atmelice_isp -p atmega32u4 -P usb -U lfuse:w:0xff:m -U hfuse:w:0x18:m -U efuse:w:0xcb:m

2) openocd cli for atmel via jtag to arduino micro
openocd -f interface/cmsis-dap.cfg -c "set CHIPNAME atmega32u4" -c "source [find target/atmega32u4.cfg]"

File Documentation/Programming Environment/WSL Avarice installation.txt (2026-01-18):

WSL Avarice install

############################################################################################################################
open a WSL terminal
############################################################################################################################
Update and upgrade WSL:
<user>@<computer>:~$ sudo apt update && sudo apt upgrade -y
[sudo] password for gerald:
Get:1 http://security.ubuntu.com/ubuntu noble-security InRelease [126 kB]
Hit:2 http://archive.ubuntu.com/ubuntu noble InRelease
Get:3 http://archive.ubuntu.com/ubuntu noble-updates InRelease [126 kB]
...
Get:45 http://security.ubuntu.com/ubuntu noble-security/multiverse amd64 c-n-f Metadata [384 B]
Fetched 13.6 MB in 4s (3207 kB/s)

Reading package lists... Done
Building dependency tree... Done
Reading state information... Done

109 packages can be upgraded. Run 'apt list --upgradable' to see them.

Reading package lists... Done
Building dependency tree... Done
Reading state information... Done
Calculating upgrade... Done

The following packages were automatically installed and are no longer required:
  libdrm-nouveau2 libdrm-radeon1 libgl1-amber-dri libglapi-mesa libllvm19 libxcb-dri2-0
Use 'sudo apt autoremove' to remove them.

The following NEW packages will be installed:
  libllvm20

The following packages have been kept back:
  libgl1-amber-dri

The following packages will be upgraded:
  apparmor apt apt-utils base-files binutils binutils-common binutils-x86-64-linux-gnu bsdextrautils bsdutils cloud-init coreutils dconf-gsettings-backend
  ...
  ubuntu-pro-client-l10n ubuntu-release-upgrader-core udev update-manager-core util-linux uuid-runtime wsl-pro-service wsl-setup

108 upgraded, 1 newly installed, 0 to remove and 1 not upgraded.
23 standard LTS security updates
Need to get 137 MB of archives.
After this operation, 163 MB of additional disk space will be used.

Get:1 http://archive.ubuntu.com/ubuntu noble-updates/main amd64 motd-news-config all 13ubuntu10.3 [4016 B]
...
Get:109 http://archive.ubuntu.com/ubuntu noble-updates/main amd64 wsl-setup amd64 0.5.10~24.04 [20.4 kB]
Fetched 137 MB in 12s (11.6 MB/s)

Extracting templates from packages: 100%

Preconfiguring packages ...
Reading database ...
Preparing to unpack ...
Unpacking ...
Setting up ...
Installing ...
Removing ...
Processing triggers ...

############################################################################################################################
install avarice:
<user>@<computer>:~$ sudo apt install avarice
Reading package lists... Done
Building dependency tree... Done
Reading state information... Done

The following packages were automatically installed and are no longer required:
  libdrm-nouveau2 libdrm-radeon1 libgl1-amber-dri libglapi-mesa libllvm19 libxcb-dri2-0
Use 'sudo apt autoremove' to remove them.

The following additional packages will be installed:
  gdb-avr libhidapi-libusb0 libusb-0.1-4

Suggested packages:
  gdb-doc

The following NEW packages will be installed:
  avarice gdb-avr libhidapi-libusb0 libusb-0.1-4

0 upgraded, 4 newly installed, 0 to remove and 1 not upgraded.
Need to get 3690 kB of archives.
After this operation, 11.6 MB of additional disk space will be used.
Do you want to continue? [Y/n] Y

Get:1 http://archive.ubuntu.com/ubuntu noble/universe amd64 libhidapi-libusb0 amd64 0.14.0-1build1 [17.6 kB]
Get:2 http://archive.ubuntu.com/ubuntu noble/main amd64 libusb-0.1-4 amd64 2:0.1.12-35build1 [17.2 kB]
Get:3 http://archive.ubuntu.com/ubuntu noble/universe amd64 avarice amd64 2.14+svn427-1 [104 kB]
Get:4 http://archive.ubuntu.com/ubuntu noble/universe amd64 gdb-avr amd64 13.2-3ubuntu3 [3551 kB]
Fetched 3690 kB in 2s (2438 kB/s)

Selecting previously unselected package libhidapi-libusb0:amd64.

Reading database ...
Preparing to unpack ...
Unpacking ...
Setting up ...
Processing triggers ...

############################################################################################################################

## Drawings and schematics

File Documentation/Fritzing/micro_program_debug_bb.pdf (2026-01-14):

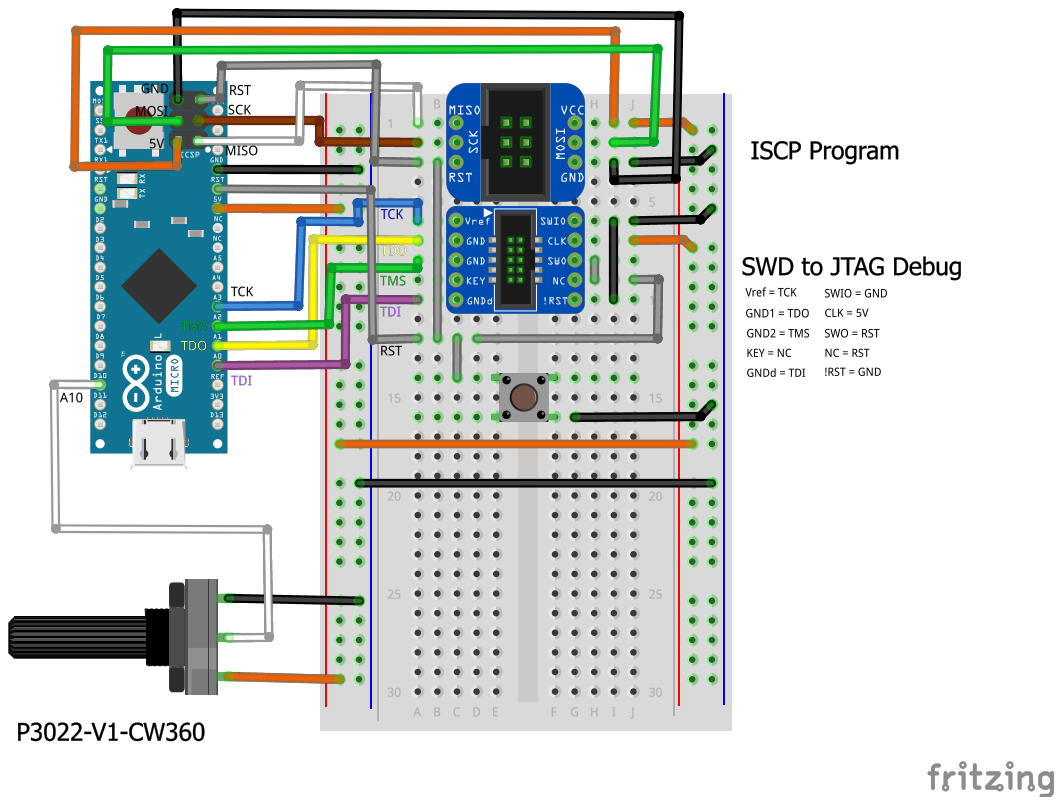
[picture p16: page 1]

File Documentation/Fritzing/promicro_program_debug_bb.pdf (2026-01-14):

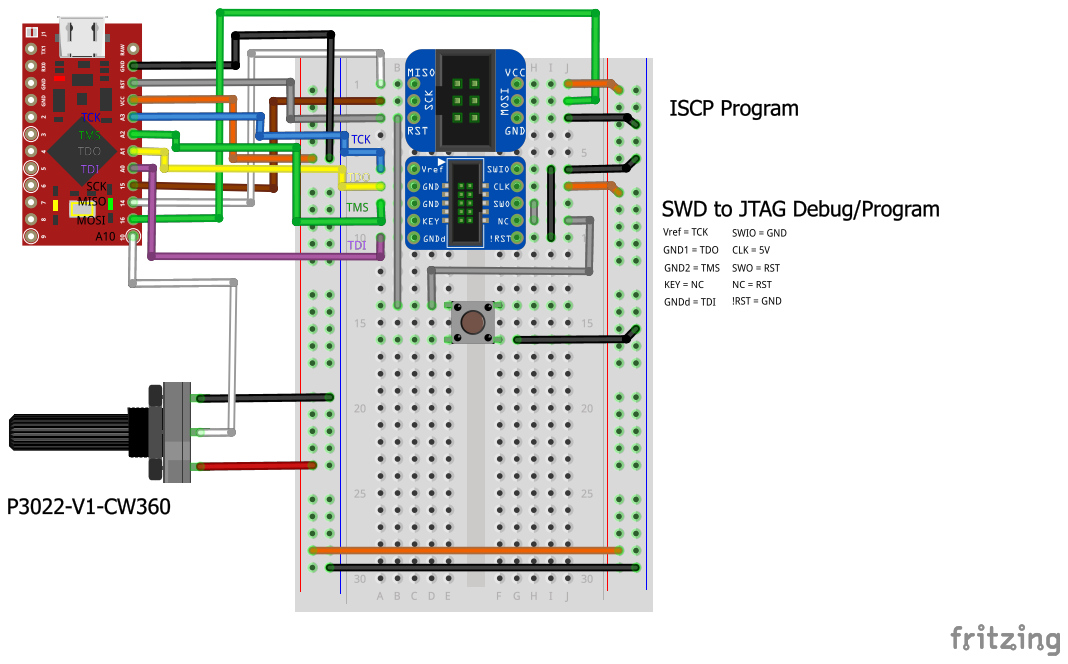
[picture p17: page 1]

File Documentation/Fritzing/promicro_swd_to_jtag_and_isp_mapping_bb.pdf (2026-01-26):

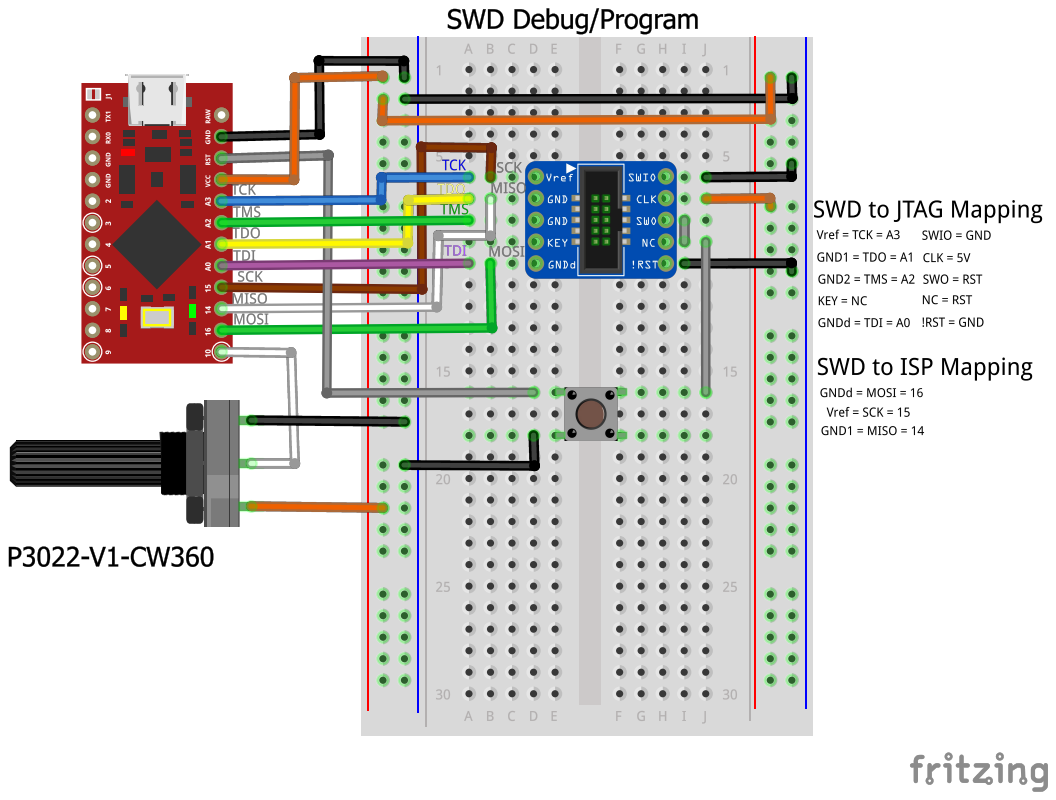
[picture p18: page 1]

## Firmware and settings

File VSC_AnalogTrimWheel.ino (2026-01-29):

// Main include file for the Arduino SDK
#include <Arduino.h>

/*
* https://github.com/dxinteractive/ResponsiveAnalogRead
* In the Arduino IDE, go to Sketch > Include libraries > Manage libraries
* search for ResponsiveAnalogRead
* Click Install
* The library's examples will now appear under File > Examples > ResponsiveAnalogRead
*/
#include "ResponsiveAnalogRead.h"

/*
* https://github.com/MHeironimus/ArduinoJoystickLibrary
* Works with Arduino Leonardo (Pro Micro) & Micro
* Does NOT work with Arduino Uno & Mega
* Download https://github.com/MHeironimus/ArduinoJoystickLibrary/archive/master.zip
* In the Arduino IDE, select Sketch > Include Library > Add .ZIP Library...
* Browse to where the downloaded ZIP file is located and click Open
* The library's examples will now appear under File > Examples > Joystick
* Alternatively,
* extract the library from zip file, rename directory to ArduinoJoystick,
* move it to Library directory that is sibling to Arduino Sketch directory
* specified in ArduinoIDE preferences
*/
#include "Joystick.h"

/*
* Sketch development parameters
*/

// serial conn speed
constexpr long BAUD = 115200;

// false for production, true for dev/debugging
constexpr bool DEBUG = false;

// for debug print statements & production mcu load easing
constexpr int DELAY = 50;

/*
* ResponsiveANalogRead parameters
*/

// sensor activity threshold
constexpr float ACTIVITY_THRESH = 1.0;

// sensor read easing on/off
constexpr bool SLEEP_ENABLE = true;

// sensor read easing amount
constexpr float SNAP_MULTIPLIER = 0.125;

/*
* P3022-V1-CW360 parameters
*/

// sensor output pin used by Arduino board
// using A10 because want A0 - A3 available for debugging
constexpr int ANALOG_PIN = A10;

// one full rotation of sensor axle is 2^10, as Arduino's can only handle 10 bit ADC
constexpr int JOY_ADC = 1024;

// 2^12 - 1 is analog to digital converter for P3022-V1-CW360 per datasheet
constexpr int SENSOR_ADC = 4096;

/*
* Sketch parameters
*/

/*
The amount of sensor turns available.
increasing revs results in MORE rotation required to effect same amount of change.
decreasing revs results in LESS rotation required to effect same amount of change.
*/
constexpr int FULL_REVS = 8;

/*
The threshold value is used to limit the rate of rotation change.
larger divisor means smaller delta rotation allowable.
smaller divisor means larger delta rotation allowable.
*/
constexpr int FULL_ROTATION_DIFF_THRESHOLD = JOY_ADC / 4;

// the full range of trim wheel response
constexpr int MAX_RANGE = FULL_REVS * JOY_ADC;

// the min range of trim wheel response
constexpr int MIN_RANGE = 0;

// very basic instantiate joystick library
// HID report id, HID input device type
// no buttons or hats
// no x, y, z axes
// no rx axis, use ry axis, no rz axis
// no rudder, throttle
// no accelerator, brake, steering
Joystick_ Joystick(JOYSTICK_DEFAULT_REPORT_ID, JOYSTICK_TYPE_GAMEPAD,
                   0, 0,
                   false, false, false,
                   false, true, false,
                   false, false,
                   false, false, false);

// the initial joystick & sensor values
int prevJoystick;
int prevSensor;

// instantiate sensor read library with overloaded method so we don't have to 2 stage initialize
ResponsiveAnalogRead sensorReader(ANALOG_PIN, false);


/**
* @brief Gets current sensor reading.
* @return {int} currentSensor The current sensor value.
*/
int currentSensor() {
  int currentSensor;

  // need to update with raw value from sensor before getting a responsive value based off it
  sensorReader.update();
  currentSensor = sensorReader.getValue();

  return currentSensor;
}


/**
* @brief Gets the sensor delta constrained to the defined threshold of rotation.
* @details Acts as a rotation rate limiter.
* @param {int} oldSensor Previous sensor value.
* @param {int} newSensor New sensor value.
* @return {int} sensorDiff Constrained sensor value.
*/
int sensorDelta(int oldSensor, int newSensor) {
  int sensorDiff;

  // initial value presuming user stayed within delta rotation threshold
  sensorDiff = newSensor - oldSensor;

  // enough clockwise (positive) input from user, ignore new sensor input
  if(sensorDiff > FULL_ROTATION_DIFF_THRESHOLD) {
    sensorDiff = sensorDiff - newSensor;
  }

  // enough counter-clockwise (negative) input from user, restore old sensor value
  if(sensorDiff < -FULL_ROTATION_DIFF_THRESHOLD) {
    sensorDiff = oldSensor + sensorDiff;
  }

  // IFF we fall through both blocks, we return the initial value
  return sensorDiff;
}


/**
* @brief Enforce the user's input to specified min/max joystick range constants.
* @param {int} joystickInput Movement input by user.
* @return {int} enforcedJoystick Enforced joystick value.
*/
int enforceJoystickRange(int joystickInput) {
  /*
  constrain accepts int, long, float and double, and returns a value of the same type as its input argument
  however, you could get implicit type conversions, so best practice to pass all variables as same type
  */

  int enforcedJoystick;

  enforcedJoystick = constrain(joystickInput, MIN_RANGE, MAX_RANGE);

  return enforcedJoystick;
}

/**
 * @brief Initialize environment for program
 * @details Runs exactly once at beginning of program lifecycle
 */
void setup() {
  // enables print output for dev/debugging purposes
  if (DEBUG) {
    Serial.begin(BAUD);
  }

  // P3022-V1-CW360 is 12 bit (4096) ADC, not 10 bit like arduino pro micro (leonardo) & micro
  sensorReader.setAnalogResolution(SENSOR_ADC);

  if(SLEEP_ENABLE) {
    // enabling sleep will cause values to take less time to stop changing and potentially stop changing more abruptly
    sensorReader.enableSleep();

    // edge snap ensures that values at the edges of the spectrum (0 and 1023) can be easily reached when sleep is enabled
    sensorReader.enableEdgeSnap();

    // snapMultiplier - a value from 0 to 1 that controls the amount of easing
    // increase this to lessen the amount of easing (such as 0.1) and make the responsive values more responsive
    // but doing so may cause more noise to seep through if sleep is not enabled
    sensorReader.setSnapMultiplier(SNAP_MULTIPLIER);

    // the amount of movement that must take place to register as activity and start moving the output value
    sensorReader.setActivityThreshold(ACTIVITY_THRESH);
  } else {
    // reset everything to defaults
    sensorReader.disableEdgeSnap();
    sensorReader.disableSleep();
    sensorReader.setSnapMultiplier(0.01);
    sensorReader.setActivityThreshold(4.0);
  }

  // set initial sensor and joystick values
  prevSensor = currentSensor();

  // while arduino map function is written to use all longs, you can supply all ints
  prevJoystick = map(prevSensor, MIN_RANGE, JOY_ADC, MIN_RANGE, MAX_RANGE);

  Joystick.begin();
  Joystick.setRyAxisRange(MIN_RANGE, MAX_RANGE);

  // ArduinoJoystickLibrary is expecting int32_t (long) type
  Joystick.setRyAxis(static_cast<long>(prevJoystick));
}

/**
 * @brief Core engine of program
 * @details Executes indefinitely, providing active control
 */
void loop() {
  long axisValue;
  int joystickMove;
  int newJoystick;
  int newSensor;
  int sensorThresh;

  // sensor rotation delta value gives us our sensitivity to change
  newSensor = currentSensor();
  sensorThresh = sensorDelta(prevSensor, newSensor);

  // once we accumulate our joystick value, need to keep it within operating range
  joystickMove = prevJoystick + sensorThresh;
  newJoystick = enforceJoystickRange(joystickMove);

  // ArduinoJoystickLibrary is expecting int32_t (long) type
  axisValue = static_cast<long>(newJoystick);
  Joystick.setRyAxis(axisValue);

  if (DEBUG) {
    long maxJoystick = 65536;
    long rotationValue;

    // map the rx axis value, 0 to (max turns * full turn), 0 to 2^16
    rotationValue = map(axisValue, MIN_RANGE, MAX_RANGE, MIN_RANGE, maxJoystick);

    if (rotationValue < MIN_RANGE) {
      rotationValue = MIN_RANGE;
    } else if (rotationValue > maxJoystick) {
      rotationValue = maxJoystick;
    }

    // Serial.print has limitations that sprintf doesn't, but sprintf needs different setup
    char printBuffer[150];
    sprintf(
      printBuffer,
      "Prev sensor: %d | New sensor: %d | Sensor diff: %d | Prev joy: %d | Joy move: %d | New joystick %d | RX axis value: %ld | RX value: %ld",
      prevSensor, newSensor, sensorThresh, prevJoystick, joystickMove, newJoystick, axisValue, rotationValue
    );
    Serial.println(printBuffer);
    delay(DELAY);
  }

  prevJoystick = newJoystick;
  prevSensor = newSensor;

  // always need a little delay so mcu doesn't get overwhelmed (the good old Apollo 11 1204 error!)
  if(!DEBUG) {
    delay(DELAY);
  }
}

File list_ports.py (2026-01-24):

#!/usr/bin/env python3
'''
@file list_ports.py
@brief Lists active COM ports
@details From google search: vs code tasks.json input com ports extension "Command Variable"

@author Gerald Manweiler
@copyright @showdate "%Y" GWN Software. All rights reserved.
'''

# standard modules
import serial.tools.list_ports
import sys


def list_com_ports():
    '''
    @brief Lists active COM ports
    @details Called by tasks.json input rule to supply list of com ports for selection
    '''

    ports = serial.tools.list_ports.comports()
    if not ports:
        print("No COM ports found")
        sys.exit(1)
    for port in ports:
        # The task will use each line as a selection option
        if port.vid and port.vid:
            print(port.device)


if __name__ == "__main__":
    list_com_ports()

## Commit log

2025-12-31 working arduino cli and openocd tasks
2025-12-31 working JTAG/ICE with WSL & aDMIN POWERSHELL setup
2025-12-31 fuse settings
2026-01-14 source stl files for 3d printer
    [base.3mf, base.stl, lid.3mf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]
2026-01-14 creality print 3mf and gcodes
    [base.3mf, spacer_tensioner.3mf]
2026-01-14 assembly instructions
2026-01-14 more docs
    [micro_program_debug.fzz, pro_micro_program_debug.fzz]
2026-01-24 working fuse reading task
2026-01-26 3d printing updates
    [1_65 inch clamp screw and plate.3mf, 2_75 inch clamp vise.3mf, 3 inch clamp.3mf]
2026-01-26 fritzing update
    [pro_micro_program_debug.fzz, promicro_production.fzz, promicro_program_debug.fzz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]
2026-01-26 testing image insertion
2026-01-26 added dev board info
2026-01-29 added assembly tips
2026-02-23 updates and new stl file
    [Base_opt_arduino_micro.stl, micro_swd_to_jtag_and_isp_mapping.fzz, promicro_swd_to_jtag_and_isp_mapping.fzz]
